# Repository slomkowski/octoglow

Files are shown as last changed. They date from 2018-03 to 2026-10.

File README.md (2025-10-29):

# Octoglow VFD - Fallout-inspired post-apocalyptic display

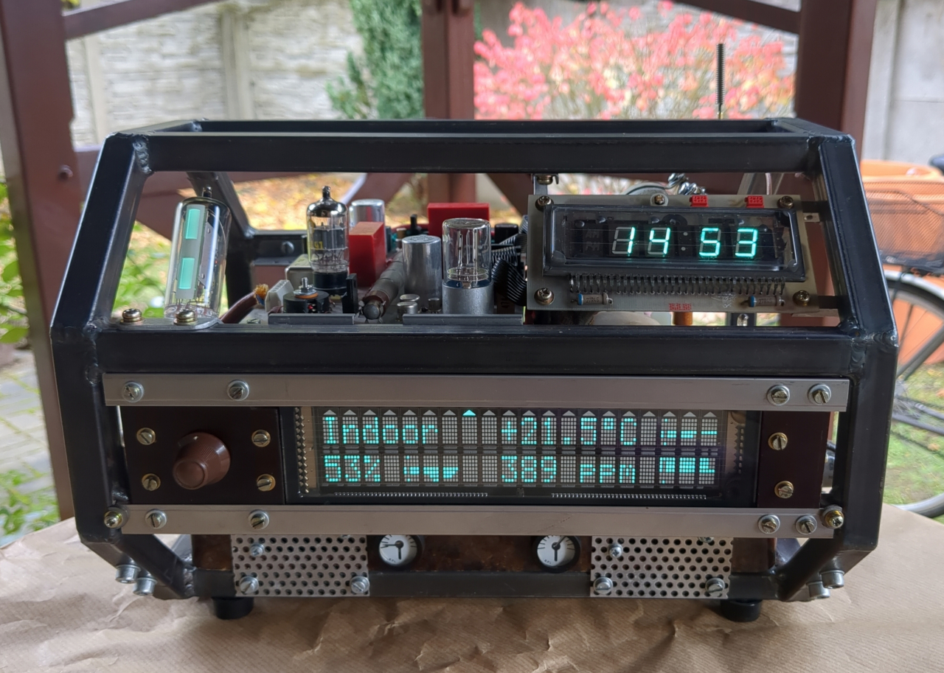
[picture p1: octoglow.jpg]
Overview


Design files of Octoglow, the post-apocalyptic desktop display device. Detailed article [published on my website](https://slomkowski.eu/octoglow-vfd-fallout-inspired-display/).

(C) Michał Słomkowski

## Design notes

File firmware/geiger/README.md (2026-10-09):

# Octoglow VFD - Geiger counter and magic eye board firmware

Written in C++ for MSP430. Depends on *libfixmath* to perform fixed-point arithmetic.

More details under https://slomkowski.eu/octoglow-vfd-fallout-inspired-display/

Tests (`test/`) run on the host with GoogleTest, ASan and UBSan.

## Bootloader

The firmware can be updated over I2C. The bootloader in `bootloader/` is a C++ port of
[twiboot](https://github.com/orempel/twiboot) (GPLv2) for MSP430G2553 with USCI_B0, compatible with its protocol,
like the ones of the clock display and the front display. MSP430 has no boot section, so the bootloader lives at the end
of the flash (`0xFC00`-`0xFFFF`, `BOOTLOADER_START` in `CMakeLists.txt`) together with the real vector table.
The reset vector starts the bootloader, the other vectors jump through the vector table of the application,
which is linked just below the bootloader (`0xFBE0`, see `msp430/application.ld.in`); it costs 3 cycles per interrupt.
The bootloader is never erased. The application is limited to 15 kB including its vector table, enforced by the linker.
The protocol logic (`bootloader/twiboot.cpp`) is covered by the host tests.

* After every reset, the bootloader listens on I2C address `0x19` for 1 s, then starts the application.
  The PWM outputs of the inverters and the heaters of the magic eye are switched off meanwhile.
* The application enters the bootloader on command `ENTER_BOOTLOADER` (`0x08`) with payload `BOOT`:
  it replies and resets (invalid watchdog password) 100 ms later.
* The addresses of the protocol are relative to the start of the flash (`0xC000`), the host subtracts it.
  The page has 64 bytes, the 512-byte segment is erased when its first page is written. The page is written after STOP,
  the host waits 30 ms before reading it back.
* Writing page 0 erases the vector table of the application, its reset vector is written as the last page.
  Without it, the bootloader doesn't time out, so an interrupted update can be repeated.
* The information memory isn't touched, the segment A holds the DCO calibration both the bootloader and the
  application rely on.

First installation (programmer): `burn.sh` writes the application and the bootloader.
Note that programming only the application with `mspdebug prog` erases the bootloader.

Update over I2C:

* `burn-over-ssh.sh` builds the firmware and burns it with `octoglowd --burn-firmware geiger` on the `octoglow` host.
* `flash-over-i2c.sh <app.hex> <bus>` on the host, with *octoglowd* stopped, uses the twiboot tool.

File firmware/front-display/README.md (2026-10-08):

# Octoglow VFD - main display board firmware

More details under https://slomkowski.eu/octoglow-vfd-fallout-inspired-display/

Compiled under *avr-gcc*, *CMake* required. Tests (`test/`) run on the host with GoogleTest, ASan and UBSan.

## Display timing

The display is multiplexed: each of the 40 characters gets a 130 µs slot timed by Timer1 (192 Hz for the whole
display). The brightness is the on-time of CL (PB2, OC1B), cleared by Timer1 in hardware, so neither the brightness
nor the refresh rate depends on the generated code. The scrolling text moves by one column every 39 ms, counted
by the 1 ms tick of Timer0. The values reproduce the firmware which timed both by the code (the -O2 build).

## Bootloader

The firmware can be updated over I2C. The bootloader in `bootloader/` is a C++ port of
[twiboot](https://github.com/orempel/twiboot) (GPLv2) for ATmega88P with the TWI peripheral, compatible with its
protocol and host tool, like the one of the clock display. It lives in the boot section at `0x1800`-`0x1FFF`
(`BOOTSZ` = 1024 words), `BOOTRST` fuse makes every reset start it, so the vector table isn't patched.
The application is limited to 6144 bytes, enforced by the linker. The protocol logic (`bootloader/twiboot.cpp`)
is covered by the host tests.

* After every reset, the bootloader listens on I2C address `0x15` for 1 s, then starts the application.
  Meanwhile, the display shows `BOOTLOADER`, the upper bar blinks while the host talks to it.
* The application enters the bootloader on command `ENTER_BOOTLOADER` (`0x0a`) with payload `BOOT`:
  it replies, shows `Entering bootloader`, stops feeding the watchdog and resets within 250 ms.

First installation (ISP): `burn.sh` writes `octoglow-front-display-avr-with-bootloader.hex` (application + bootloader)
and sets `efuse` to `0xf8` (`BOOTRST` programmed, `BOOTSZ` = 1024 words).
Note that flashing only `octoglow-front-display-avr.hex` with ISP erases the bootloader.

Update over I2C:

* `burn-over-ssh.sh` builds the firmware and burns it with `octoglowd --burn-firmware front-display` on the `octoglow` host.
* `flash-over-i2c.sh <app.hex> <bus>` on the host, with *octoglowd* stopped, uses the twiboot tool.

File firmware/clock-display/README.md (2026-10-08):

# Octoglow VFD - clock display board firmware

Compiled under *avr-gcc*, *CMake* required. *burn.sh* - flashing.

More details under https://slomkowski.eu/octoglow-vfd-fallout-inspired-display/

## Bootloader

The firmware can be updated over I2C. The bootloader in `bootloader/` is a C++ port of
[twiboot](https://github.com/orempel/twiboot) (GPLv2) reduced to ATtiny461A with USI, compatible with its protocol
and host tool. ATtiny461A has no boot section, so the bootloader lives at `0x0C40`-`0x0FFF` and patches the
vector table: the reset vector jumps to the bootloader and the `EE_RDY` vector (must not be used by the
application) jumps to the application. The application is limited to 3136 bytes, enforced by the linker.
USI pins, register settings and both I2C addresses are shared by the application and the bootloader in `common/usi.hpp`.

* After every reset, the bootloader listens on I2C address `0x11` for 1 s, then starts the application.
  Meanwhile, the display shows `BOOT` (8, 0, 0 and T as a mirrored 7), the dots blink while the host talks to it.
* The application enters the bootloader on command `ENTER_BOOTLOADER` (`0x07`) with payload `BOOT`:
  it replies, stops feeding the watchdog and resets within 250 ms.

First installation (ISP): `burn.sh` writes `octoglow-clock-display-with-bootloader.hex` (application + bootloader
with the vector table already patched) and sets `efuse` to `0xfe` (self-programming enabled).
Note that flashing only `octoglow-clock-display.hex` with ISP erases the bootloader.

Update over I2C: `flash-over-i2c.sh <app.hex> <bus>` on the host, with *octoglowd* stopped.

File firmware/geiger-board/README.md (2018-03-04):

# Geiger board

todo jak skompilować projekt

* msp430 toolchain
* gtest
* gcc

# Bus pirate example

Write address *0x24*, read *0x25*.

```
W - enable power supply
P - enable pull-up resistors

[ 0x24 1 [ 0x25 r:8 ] - read device state
[ 0x24 2 [ 0x25 r:6 ]

```

## Animation test - `animationtest`

This program was used to easily test magic eye animation procedure. Uses code from `libsrc`. Requires SDL2 library.

* space - simulate Geiger count
* Esc - exit

## Animation idea

wartość średnia

## I2C protocol specification

status:
napięcie geiger
status przetwornicy eye
napięcie przetwornicy eye
status kontrolera eye: animation, fixed val
wartość kontrolera eye, jeśli fixed val

status geiger:
ilość zliczeń w bieżącym cyklu
ilość zliczeń w poprzednim cyklu
dł. cyklu w s

jakie komendy:
odczyt statusu:
odczyt statusu geiger
włączenie/wyłączenie oka
reset licznika geigera
tryb pracy oka: tryb + wartość dla fixed

## Read device status

Send *0x1* then read 8 bytes. Structure `DeviceState` is returned.

## Read Geiger counter status

Send *0x2* then read 6 bytes. Structure `GeigerState` is returned.

## Clean Geiger counter status

Clears all counters. Send `0x3`.

## Enable/disable magic eye 

```
0x4 | enabled

enabled:
0 - eye disabled (default)
1 - eye enabled
```

# Set magic eye animation mode

```
0x5 | mode | value

mode:
0 - animation. value is ignored
1 - fixed value

value:
0-255 - DAC output
```

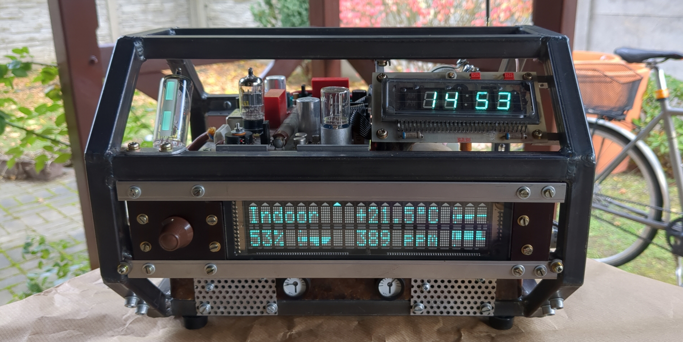
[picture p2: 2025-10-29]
social-preview.jpg

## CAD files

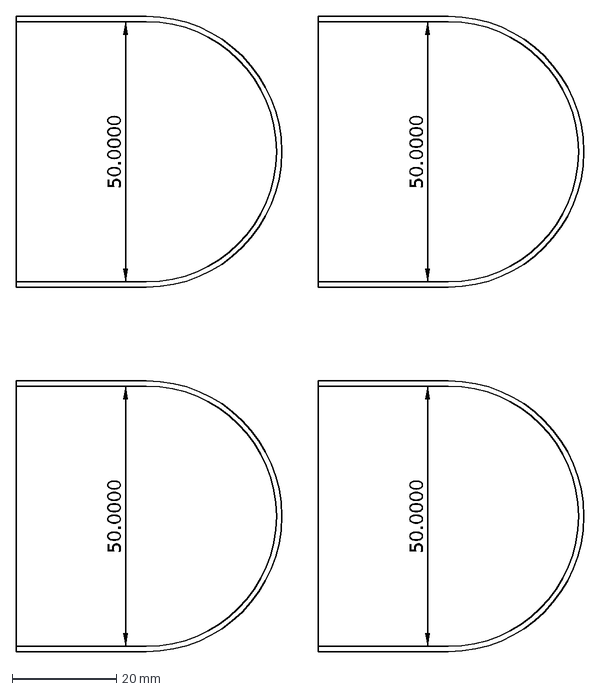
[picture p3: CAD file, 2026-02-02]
case/backlight.dxf
50.0000

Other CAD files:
case/shape.fcstd

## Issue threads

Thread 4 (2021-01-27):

Kotlin native

slomkowski, 2021-01-27:
* linux-i2c - use kernel functions directly
* logging - find other logger
* exposed - probably need to use native SQL driver https://github.com/Dominaezzz/kotlin-sqlite
* jackson & fuel
* konf
* stateful4k - rewrite to Kotlin Multiplatform

Small libs:
* suncalc
* jollyday

slomkowski, 2021-02-15:
* replace java.time with kotlinx date time.
* replace konf with something lightweight?

slomkowski, 2023-06-21:
* Kotlin target: linuxArm32Hfp

slomkowski, 2023-09-20:
linuxArm32Hfp is deprecated in Kotlin Native, so migrating to Kotlin Native it doesn't make sense unless Orange Pi Zero is changed to something else.

Closed 2023-09-20.

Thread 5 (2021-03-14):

Nowa czujka

slomkowski, 2021-03-14:
SP67.

* couple of AGC pulses
* start bit: 8 ms of carrier
* short: 2 ms
* long: 4 ms
* 40 bits
* ostatnie dwa bity z 40 to nr kanału
* bit 12 - manual TX
* bit 13 - weak battery

slomkowski, 2021-04-09:
https://www.chaosgeordend.nl/wordpress/2021/02/18/fanju-temperature-sensor-transmission-protocol/

Closed 2021-07-26.

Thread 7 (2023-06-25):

Remove Java dependencies

slomkowski, 2023-06-25:
With Kotlin libraries ready for Native transition #6.

Pure JVM:

* [ ] Jollyday
* [ ] commons-lang3
* [ ] commons-csv
* [ ] logback
* [ ] ktor - replace with snakeyaml-kmp?

Java with native libraries:
* [ ] exposed with SQLite
* [ ] linux-i2c

Closed 2025-10-05.

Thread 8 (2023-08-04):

Armbian setup

slomkowski, 2023-08-04:
zainstalowane pakiety armbian booworm:
kernel:5.15.93-sunxi
on 6.x kernel wifi doesn't work

powertop
openjdk-17-jre-headless
supervisor
https://github.com/slomkowski/bash-full-of-colors/
 most multitail pydf mtr htop
vim
iputils-ping
gpasswd -a octoglow i2c
btop

Closed 2023-09-20.

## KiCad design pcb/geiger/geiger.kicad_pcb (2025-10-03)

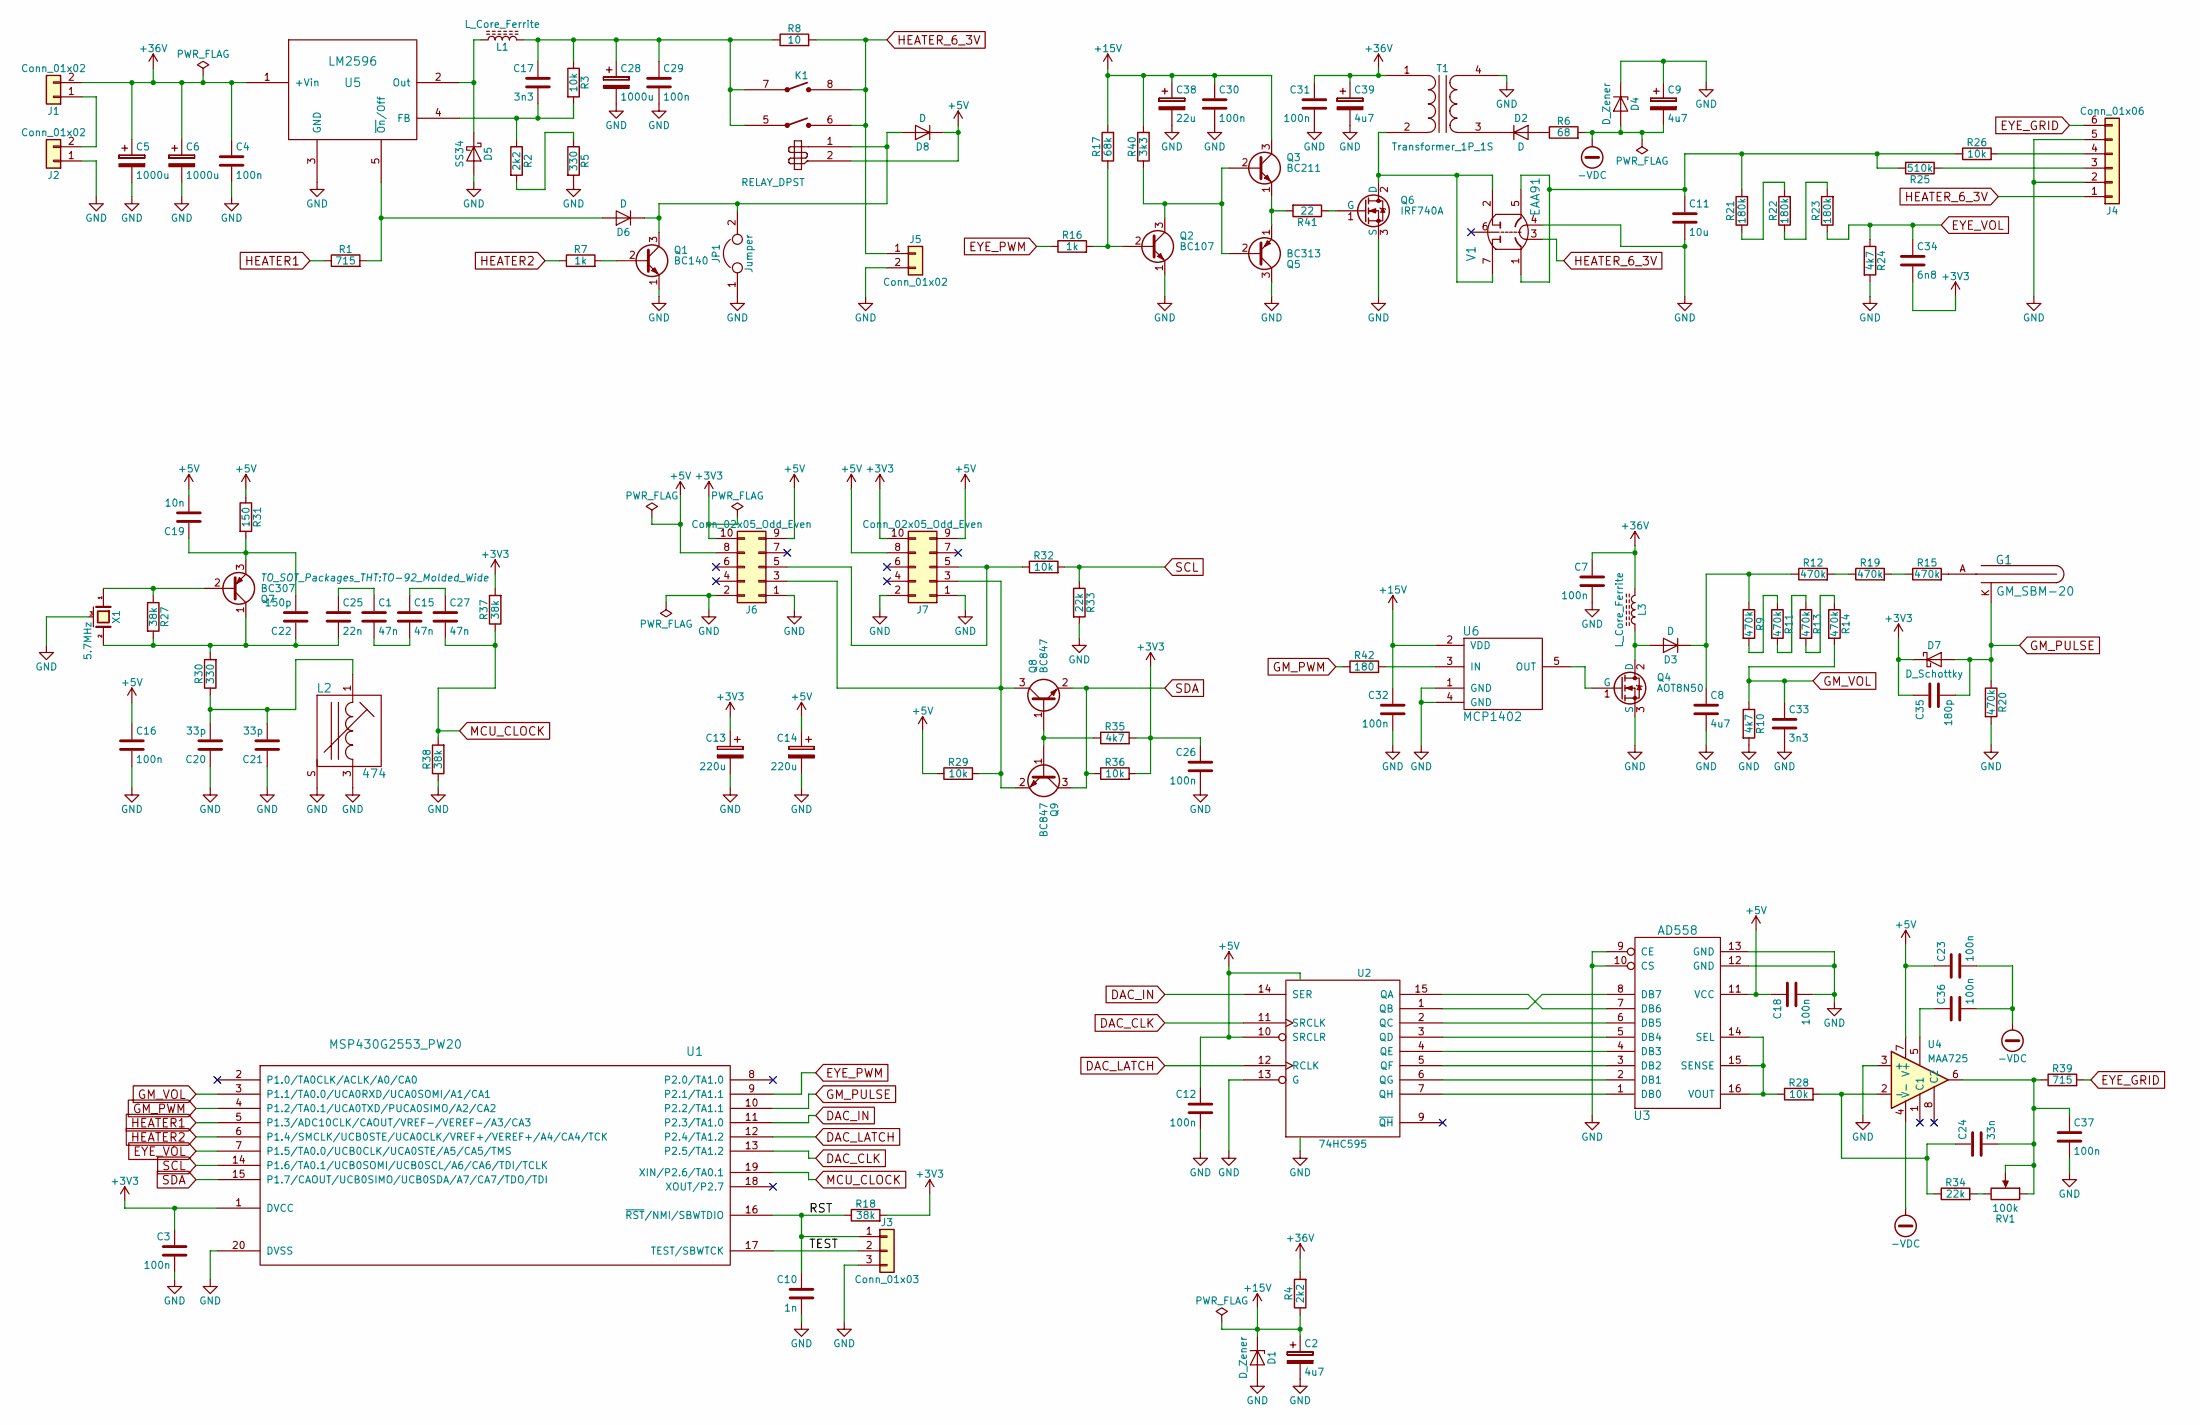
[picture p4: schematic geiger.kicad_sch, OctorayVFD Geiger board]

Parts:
C1, C15, C27: 47n; C_Disc_D5.0mm_W2.5mm_P5.00mm
C2: 4u7; CP_Radial_D6.3mm_P2.50mm
C3, C4, C7, C12, C16, C18, C23, C26, C29, C30, C31, C32, C36, C37: 100n; C_1206_HandSoldering
C5, C6: 1000u; CP_Radial_D16.0mm_P7.50mm
C8: 4u7; C_Rect_L33.0mm_W13.0mm_P27.50mm_MKS4
C9, C39: 4u7; CP_Tantalum_Case-D_EIA-7343-31_Hand
C10: 1n; C_0805_HandSoldering
C11: 10u; C_Rect_L33.0mm_W13.0mm_P27.50mm_MKS4
C13, C14: 220u; CP_Radial_D13.0mm_P5.00mm
C17, C33: 3n3; C_1206_HandSoldering
C19: 10n; C_Disc_D5.0mm_W2.5mm_P5.00mm
C20, C21: 33p; C_Disc_D5.0mm_W2.5mm_P5.00mm
C22: 150p; C_Disc_D5.0mm_W2.5mm_P5.00mm
C24: 33n; C_Disc_D11.0mm_W5.0mm_P5.00mm
C25: 22n; C_Disc_D5.0mm_W2.5mm_P5.00mm
C28: 1000u; CP_Radial_D8.0mm_P3.50mm
C34: 6n8; C_Rect_L9.0mm_W3.2mm_P7.50mm_MKT
C35: 180p; C_Rect_L9.0mm_W3.2mm_P7.50mm_MKT
C38: 22u; CP_Tantalum_Case-B_EIA-3528-21_Hand
D1, D4: D_Zener; D_DO-41_SOD81_P2.54mm_Vertical_AnodeUp
D2, D3: D; D_SMB
D5: SS34; D_SMA-SMB_Universal_Handsoldering
D6, D8: D; D_DO-41_SOD81_P12.70mm_Horizontal
D7: D_Schottky; D_DO-35_SOD27_P10.16mm_Horizontal
G1: GM_SBM-20
J1, J2, J5: Conn_01x02; TerminalBlock_Pheonix_MKDS1.5-2pol
J3: Conn_01x03; Pin_Header_Straight_1x03_Pitch2.54mm
J4: Conn_01x06; TerminalBlock_Pheonix_PT-3.5mm_6pol
J6, J7: Conn_02x05_Odd_Even; Pin_Header_Straight_2x05_Pitch2.54mm
JP1: Jumper; Pin_Header_Straight_1x02_Pitch2.54mm
K1: RELAY_DPST; RELAY_DPST_Telfa_K-8
L1: L_Core_Ferrite; Choke_SMD_12x12mm_h8mm
L2: 474; L_7x7_II
L3: L_Core_Ferrite; F1001_coil
Q1: BC140; TO-39-3
Q2: BC107; TO-18-3
Q3: BC211; TO-39-3
Q4: AOT8N50; TO-220-3_Vertical
Q5: BC313; TO-39-3
Q6: IRF740A; TO-220-3_Vertical
Q7: BC307; TO-92_Molded_Wide
Q8, Q9: BC847; SOT-23
R1: 715; R_Axial_DIN0411_L9.9mm_D3.6mm_P12.70mm_Horizontal
R2: 2k2; R_1206_HandSoldering
R3, R29, R32, R36: 10k; R_1206_HandSoldering
R4: 2k2; R_Axial_DIN0207_L6.3mm_D2.5mm_P10.16mm_Horizontal
R5: 330; R_1206_HandSoldering
R6: 68; R_Axial_DIN0309_L9.0mm_D3.2mm_P12.70mm_Horizontal
R7, R16: 1k; R_Axial_DIN0207_L6.3mm_D2.5mm_P10.16mm_Horizontal
R8: 10; R_Axial_DIN0617_L17.0mm_D6.0mm_P30.48mm_Horizontal
R9, R11, R13, R14, R20: 470k; R_1206_HandSoldering
R10, R24, R35: 4k7; R_1206_HandSoldering
R12, R15, R19: 470k; R_Axial_DIN0309_L9.0mm_D3.2mm_P12.70mm_Horizontal
R17: 68k; R_Axial_DIN0207_L6.3mm_D2.5mm_P10.16mm_Horizontal
R18, R27, R37, R38: 38k; R_1206_HandSoldering
R21, R22, R23: 180k; R_0805_HandSoldering
R25: 510k; R_Axial_DIN0309_L9.0mm_D3.2mm_P15.24mm_Horizontal
R26: 10k; R_Axial_DIN0309_L9.0mm_D3.2mm_P15.24mm_Horizontal
R28: 10k; R_Axial_DIN0207_L6.3mm_D2.5mm_P10.16mm_Horizontal
R30: 330; R_Axial_DIN0207_L6.3mm_D2.5mm_P10.16mm_Horizontal
R31: 150; R_Axial_DIN0207_L6.3mm_D2.5mm_P10.16mm_Horizontal
R33: 22k; R_1206_HandSoldering
R34: 22k; R_Axial_DIN0207_L6.3mm_D2.5mm_P10.16mm_Horizontal
R39: 715; R_Axial_DIN0309_L9.0mm_D3.2mm_P12.70mm_Horizontal
R40: 3k3; R_Axial_DIN0207_L6.3mm_D2.5mm_P10.16mm_Horizontal
R41: 22; R_Axial_DIN0309_L9.0mm_D3.2mm_P12.70mm_Horizontal
R42: 180; R_Axial_DIN0309_L9.0mm_D3.2mm_P15.24mm_Horizontal
RV1: 100k; Potentiometer_Trimmer_Bourns_3006P
T1: Transformer_1P_1S; F1001_trans
U1: MSP430G2553_PW20; DIP-20_W7.62mm_LongPads
U2: 74HC595; DIP-16_W7.62mm_LongPads
U3: AD558; DIP-16_W7.62mm_LongPads
U4: MAA725; TO-5-8_H08C
U5: LM2596; TO-263-5_TabPin3
U6: MCP1402; SOT-23-5_HandSoldering
V1: EAA91; HEPTAL1
X1: 5.7MHz; glass_xtal

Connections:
+3V3: C3.1, C13.1, C26.1, C34.2, C35.1, D7.1 (K), J6.10, J7.10, R18.2, R35.2, R36.2, R37.2, U1.1 (DVCC)
+5V: C12.1, C14.1, C16.1, C18.1, C19.2, C23.1, D8.1 (K), J6.8, J6.9, J7.8, J7.9, K1.2, R29.1, R31.1, U2.10 (SRCLR), U2.16 (VCC), U3.11 (VCC), U4.7 (V+)
+15V: C2.1, C30.1, C32.1, C38.1, D1.1 (K), Q3.3 (C), R4.1, R17.2, R40.2, U6.2 (VDD)
+36V: C4.1, C5.1, C6.1, C7.1, C31.1, C39.1, J1.2, L3.2, R4.2, T1.1 (AA), U5.1 (+Vin)
-VDC: C9.2, C23.2, C36.2, D4.2 (A), R6.2, U4.4 (V-)
/RST: C10.1, J3.1, R18.1, U1.16 (~RST/NMI/SBWTDIO)
/TEST: J3.2, U1.17 (TEST/SBWTCK)
DAC_CLK: U1.13 (P2.5/TA1.2), U2.11 (SRCLK)
DAC_IN: U1.11 (P2.3/TA1.0), U2.14 (SER)
DAC_LATCH: U1.12 (P2.4/TA1.2), U2.12 (RCLK)
EYE_GRID: J4.6, R39.2
EYE_PWM: R16.1, U1.9 (P2.1/TA1.1)
EYE_VOL: C34.1, R23.1, R24.1, U1.7 (P1.5/TA0.0/UCB0CLK/UCA0STE/A5/CA5/TMS)
GM_PULSE: C35.2, D7.2 (A), G1.K, R20.1, U1.10 (P2.2/TA1.1)
GM_PWM: R42.1, U1.4 (P1.2/TA0.1/UCA0TXD/PUCA0SIMO/A2/CA2)
GM_VOL: C33.1, R10.1, R14.2, U1.3 (P1.1/TA0.0/UCA0RXD/UCA0SOMI/A1/CA1)
GND: C2.2, C3.2, C4.2, C5.2, C6.2, C7.2, C8.2, C9.1, C10.2, C11.2, C12.2, C13.2, C14.2, C16.2, C18.2, C20.1, C21.1, C26.2, C28.2, C29.2, C30.2, C31.2, C32.2, C33.2, C37.2, C38.2, C39.2, D1.2 (A), D4.1 (K), D5.2 (A), J2.1, J3.3, J4.2, J4.5, J5.2, J6.1, J6.2, J7.1, J7.2, JP1.1, L2.3, L2.S, Q1.1 (E), Q2.1 (E), Q4.3 (S), Q5.3 (C), Q6.3 (S), R5.2, R10.2, R20.2, R24.2, R33.2, R38.1, T1.4 (SB), U1.20 (DVSS), U2.8 (GND), U2.13 (G), U3.9 (CE), U3.10 (CS), U3.12 (GND), U3.13 (GND), U4.3 (+), U5.3 (GND), U6.1 (GND), U6.4 (GND), V1.4, X1.3 (case)
HEATER1: R1.1, U1.5 (P1.3/ADC10CLK/CAOUT/VREF-/VEREF-/A3/CA3)
HEATER2: R7.1, U1.6 (P1.4/SMCLK/UCB0STE/UCA0CLK/VREF+/VEREF+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)
HEATER_6_3V: J4.1, J5.1, K1.6, K1.8, R8.2, V1.3
MCU_CLOCK: C27.2, R37.1, R38.2, U1.19 (XIN/P2.6/TA0.1)
unnamed: C1.1, C25.1
unnamed: C1.2, C15.2
unnamed: C11.1, R21.2, R25.2, R26.1, V1.1, V1.5
unnamed: C15.1, C27.1
unnamed: C17.1, C28.1, C29.1, K1.5, K1.7, L1.2, R3.1, R8.1
unnamed: C20.2, C21.2, L2.1, R30.1
unnamed: C24.2, C37.1, R39.1, RV1.1, RV1.2, U4.6
unnamed: C36.1, U4.5
unnamed: D2.2 (A), R6.1
unnamed: D2.1 (K), T1.3 (SA)
unnamed: D3.2 (A), L3.1, Q4.2 (D)
unnamed: C8.1, D3.1 (K), R9.1, R12.1
unnamed: D5.1 (K), L1.1, U5.2 (Out)
unnamed: D6.2 (A), R1.2, U5.5 (~On/Off)
unnamed: D6.1 (K), D8.2 (A), JP1.2, K1.1, Q1.3 (C)
unnamed: G1.A, R15.2
unnamed: J1.1, J2.2
unnamed: J4.3, R25.1
unnamed: J4.4, R26.2
unnamed: J6.3, J7.3, Q8.3 (C), Q9.2 (E), R29.2
unnamed: J6.5, J7.5, R32.1
unnamed: Q1.2 (B), R7.2
unnamed: Q2.2 (B), R16.2, R17.1
unnamed: Q2.3 (C), Q3.2 (B), Q5.2 (B), R40.1
unnamed: Q3.1 (E), Q5.1 (E), R41.2
unnamed: Q4.1 (G), U6.5 (OUT)
unnamed: Q6.2 (D), T1.2 (AB), V1.2, V1.7
unnamed: Q6.1 (G), R41.1
unnamed: Q7.2 (B), R27.1, X1.1
unnamed: C22.1, C25.2, Q7.1 (C), R27.2, R30.2, X1.2
unnamed: C19.1, C22.2, Q7.3 (E), R31.2
unnamed: Q8.1 (B), Q9.1 (B), R35.1
unnamed: R2.2, R5.1
unnamed: R9.2, R11.1
unnamed: R11.2, R13.1
unnamed: R12.2, R19.1
unnamed: R13.2, R14.1
unnamed: R15.1, R19.2
unnamed: R21.1, R22.2
unnamed: R22.1, R23.2
unnamed: R34.2, RV1.3
unnamed: U2.15 (QA), U3.7 (DB6)
unnamed: U2.1 (QB), U3.8 (DB7)
unnamed: U2.2 (QC), U3.6 (DB5)
unnamed: U2.3 (QD), U3.5 (DB4)
unnamed: U2.4 (QE), U3.4 (DB3)
unnamed: U2.5 (QF), U3.3 (DB2)
unnamed: U2.6 (QG), U3.2 (DB1)
unnamed: U2.7 (QH), U3.1 (DB0)
unnamed: R28.1, U3.14 (SEL), U3.15 (SENSE), U3.16 (VOUT)
unnamed: C24.1, R28.2, R34.1, U4.2 (-)
unnamed: C17.2, R2.1, R3.2, U5.4 (FB)
unnamed: R42.2, U6.3 (IN)
SCL: R32.2, R33.1, U1.14 (P1.6/TA0.1/UCB0SOMI/UCB0SCL/A6/CA6/TDI/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)
SDA: Q8.2 (E), Q9.3 (C), R36.1, U1.15 (P1.7/CAOUT/UCB0SIMO/UCB0SDA/A7/CA7/TDO/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)

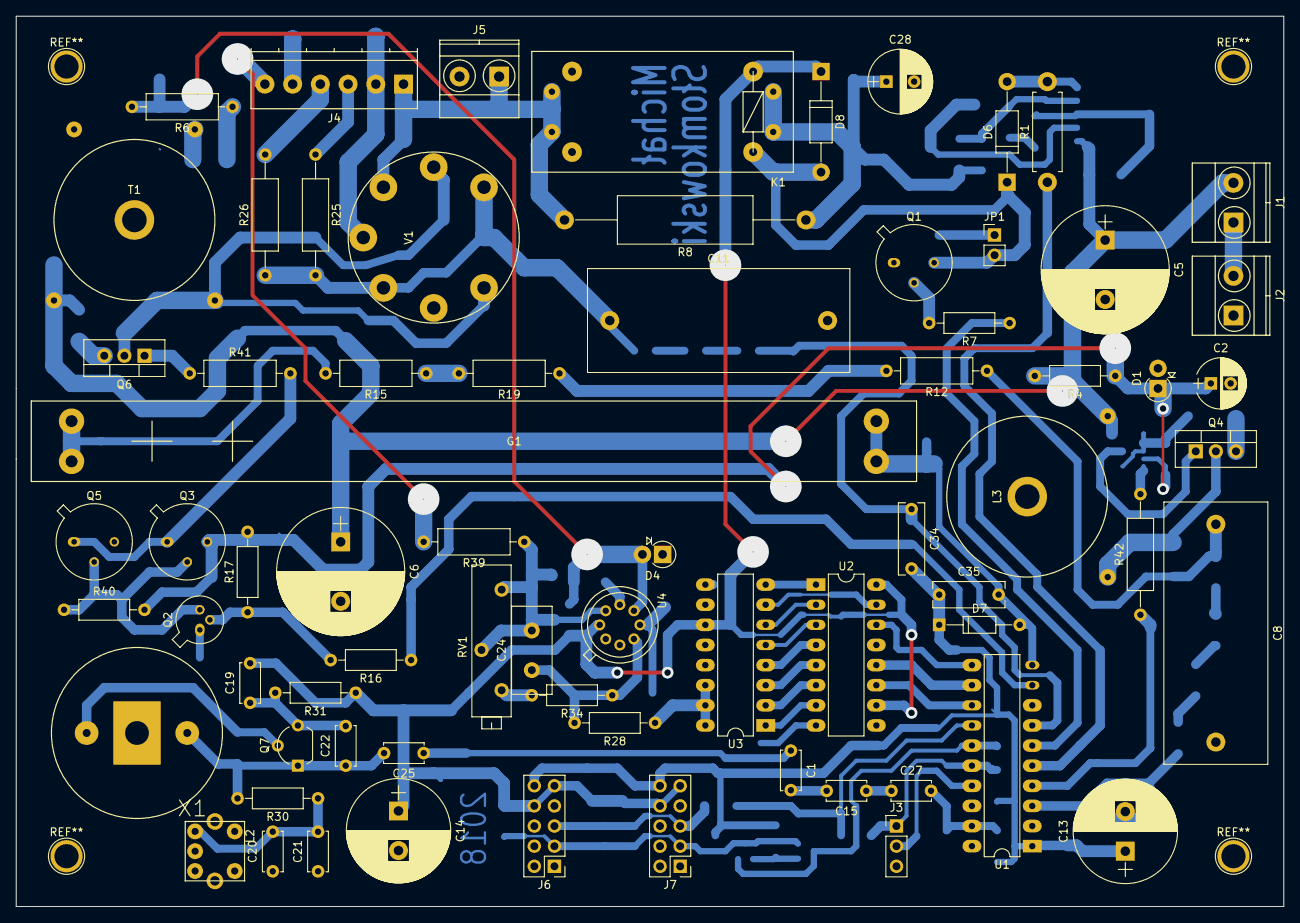
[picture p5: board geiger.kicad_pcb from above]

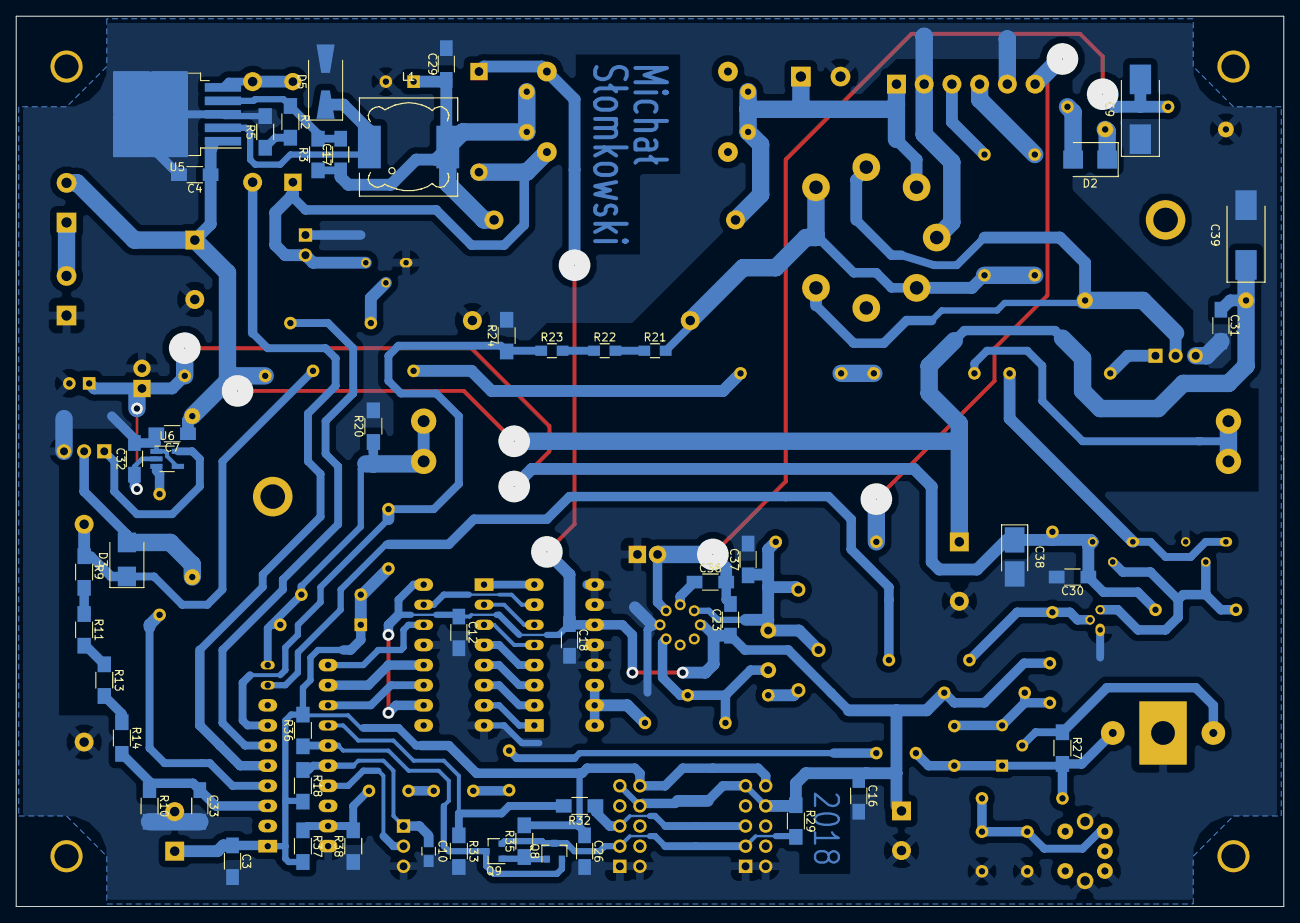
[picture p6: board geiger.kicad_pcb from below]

Board: 2 copper layers, 160.0 x 112.4 mm, 121 parts (50 on the bottom side), 76 nets.

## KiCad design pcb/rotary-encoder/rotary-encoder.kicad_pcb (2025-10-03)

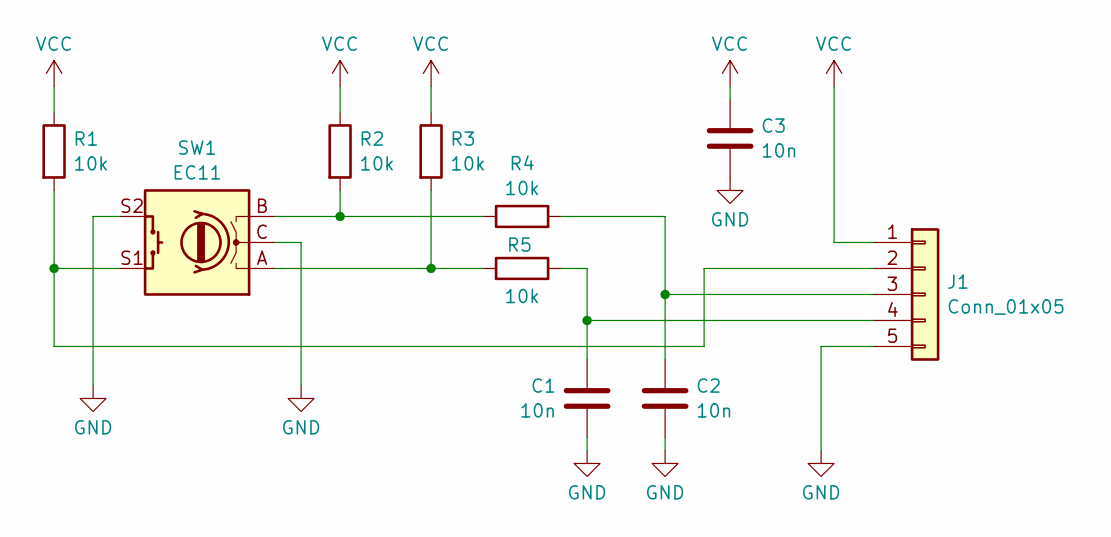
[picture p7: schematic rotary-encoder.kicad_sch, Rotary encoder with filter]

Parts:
C1, C2, C3: 10n; C_1206_3216Metric_Pad1.33x1.80mm_HandSolder
J1: Conn_01x05; PinHeader_1x05_P2.54mm_Horizontal
R1, R2, R3, R4, R5: 10k; R_1206_3216Metric_Pad1.30x1.75mm_HandSolder
SW1: EC11; RotaryEncoder_Alps_EC12E-Switch_Vertical_H20mm

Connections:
GND: C1.2, C2.2, C3.2, J1.5, SW1.C, SW1.S2
unnamed: J1.2, R1.2, SW1.S1
unnamed: C2.1, J1.3, R4.2
unnamed: C1.1, J1.4, R5.1
unnamed: R2.2, R4.1, SW1.B
unnamed: R3.2, R5.2, SW1.A
VCC: C3.1, J1.1, R1.1, R2.1, R3.1

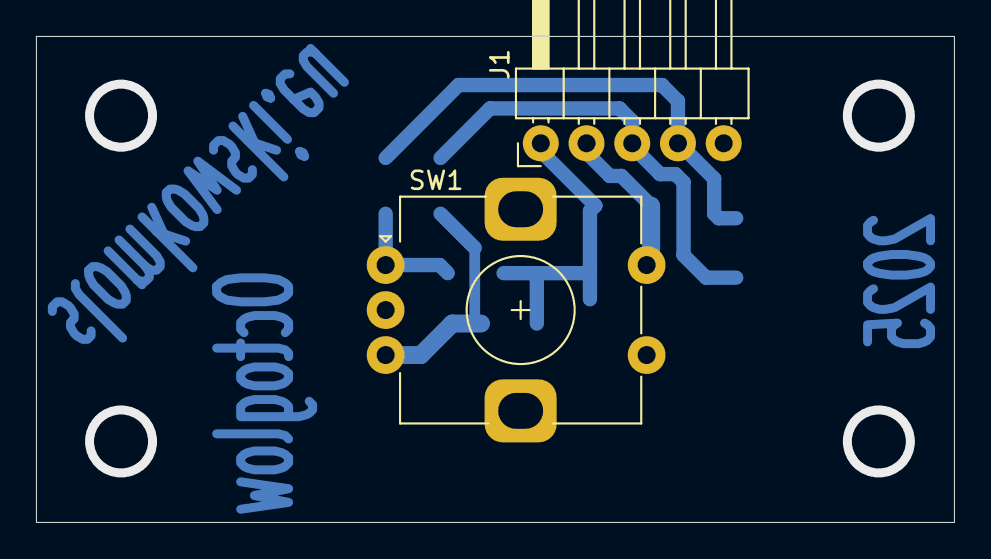
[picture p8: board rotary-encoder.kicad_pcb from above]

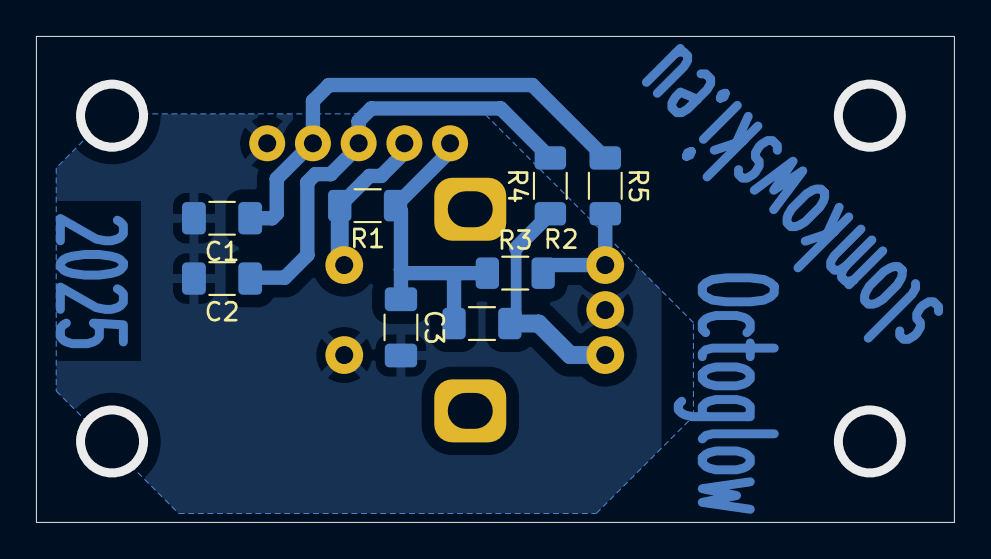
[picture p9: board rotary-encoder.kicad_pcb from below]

Board: 2 copper layers, 51.0 x 27.0 mm, 10 parts (8 on the bottom side), 7 nets.

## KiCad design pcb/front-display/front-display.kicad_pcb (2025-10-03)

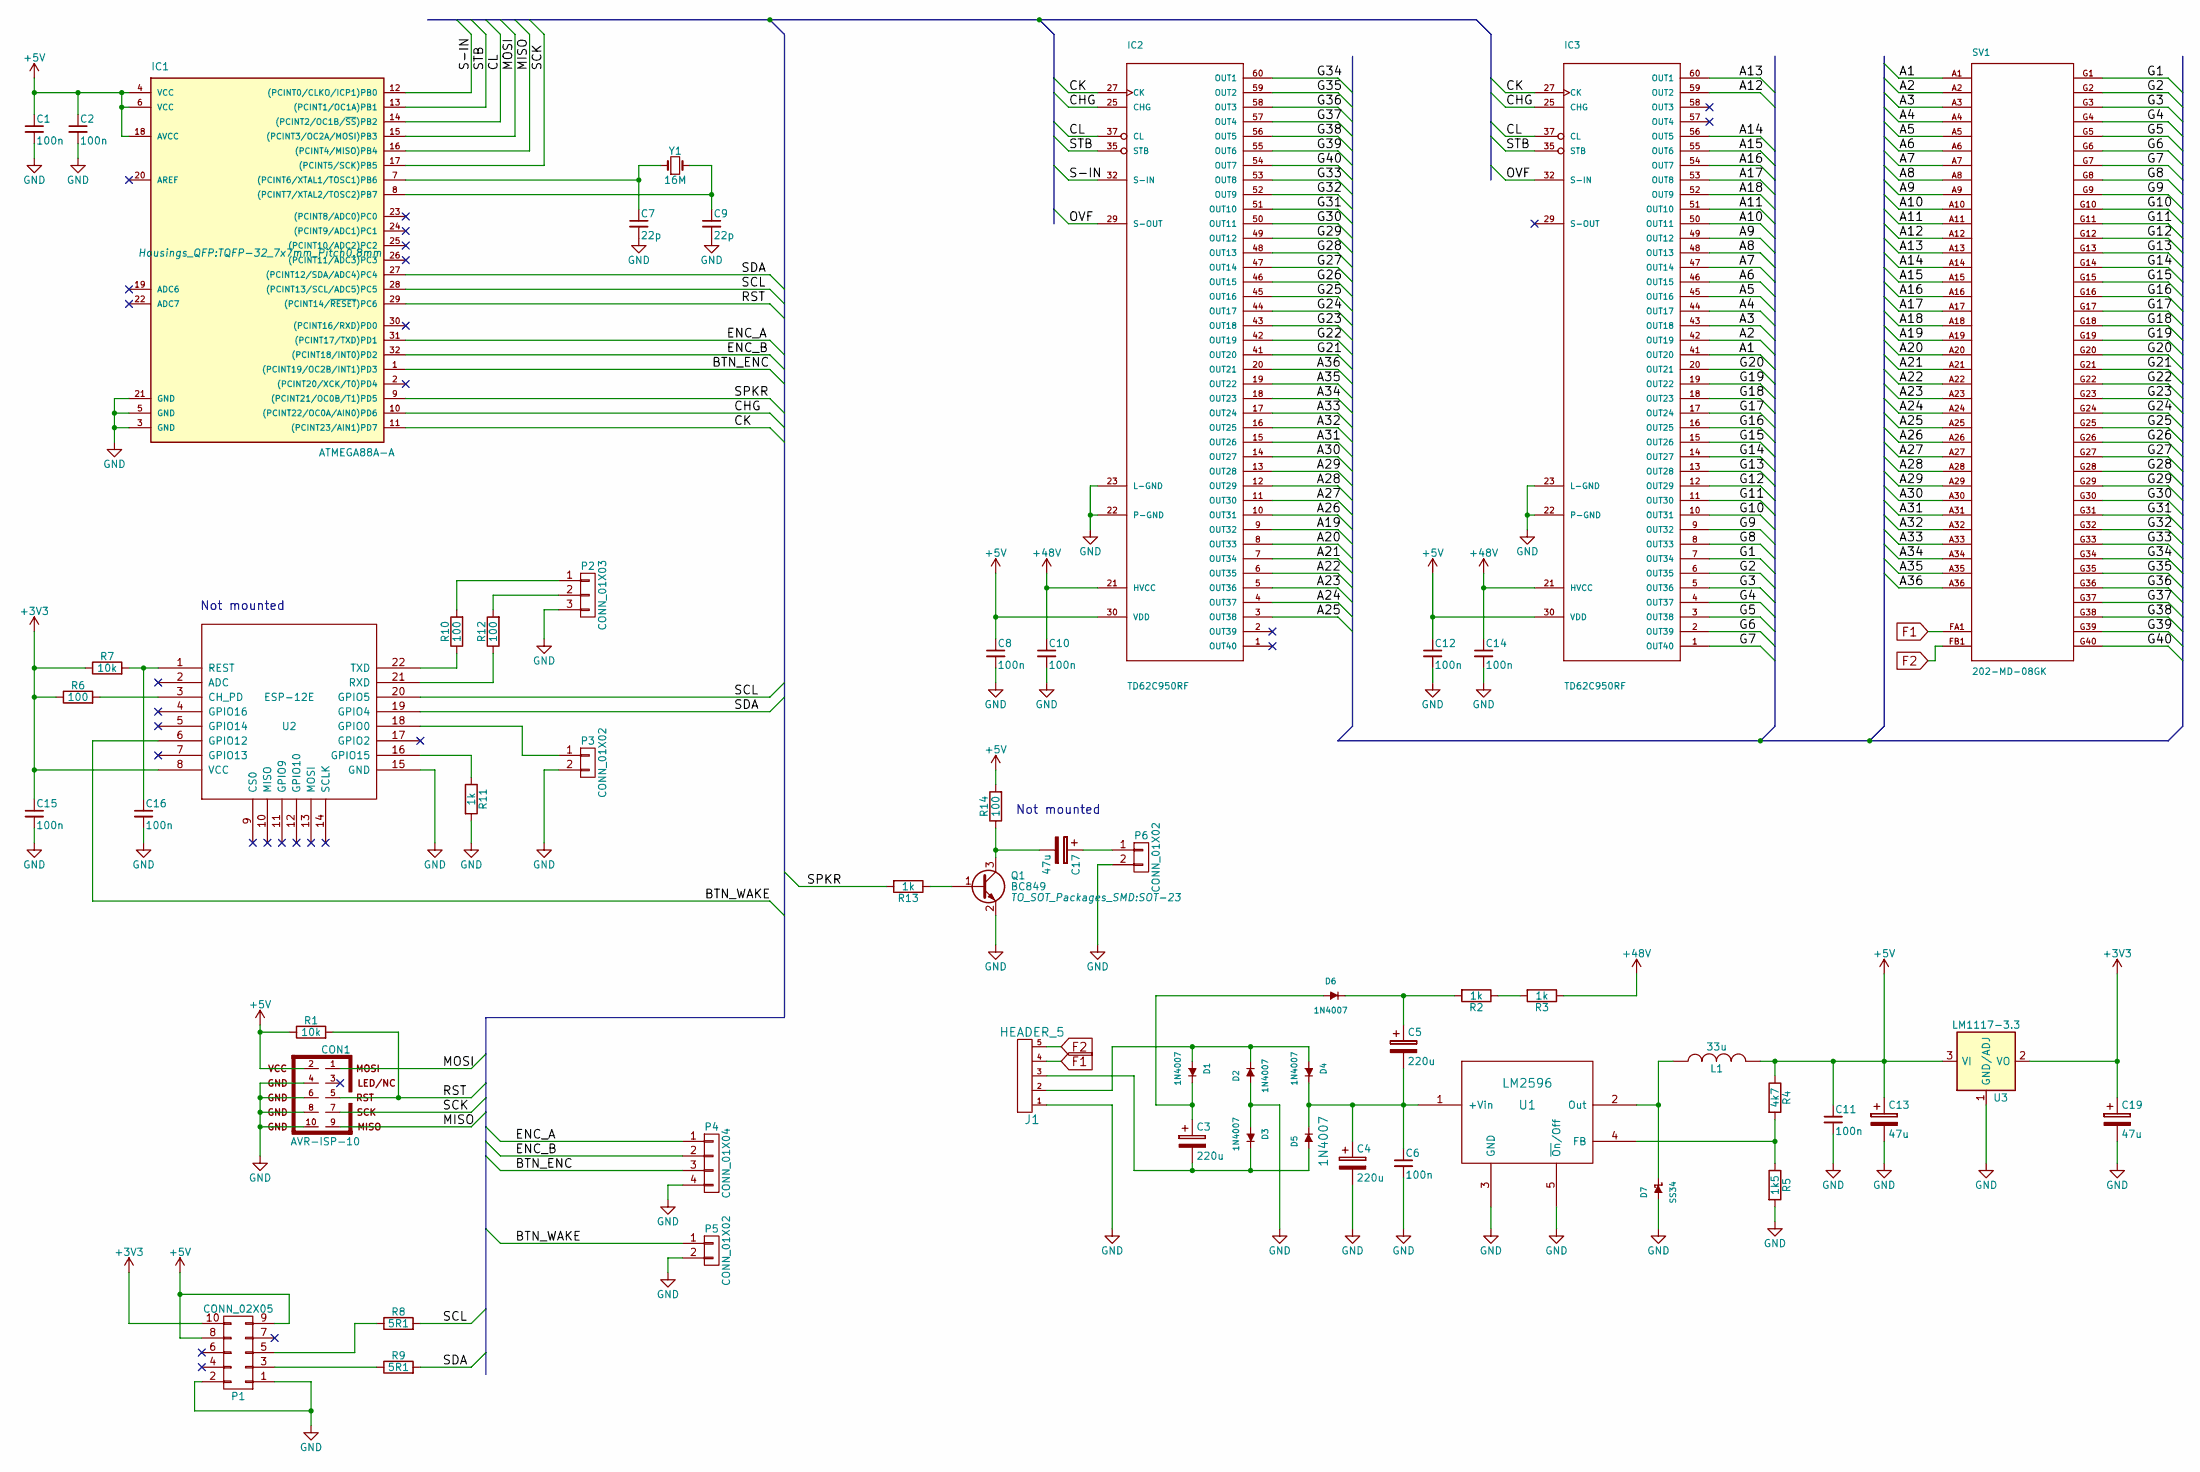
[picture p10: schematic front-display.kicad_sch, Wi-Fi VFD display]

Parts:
C1, C2, C6, C8, C10, C11, C12, C14, C15, C16: 100n; C_1206_HandSoldering
C3, C4, C5: 220u; c_elec_10x10
C7, C9: 22p; C_0805_HandSoldering
C13, C17, C19: 47u; c_elec_8x10.5
CON1: AVR-ISP-10; Pin_Header_Straight_2x05
D1, D2, D3, D4, D5, D6: 1N4007; SMA-SMB_Universal_Handsoldering
D7: SS34; SMA-SMB_Universal_Handsoldering
IC1: ATMEGA88A-A; TQFP-32_7x7mm_Pitch0.8mm
IC2, IC3: TD62C950RF; TD62C950RF-SSOP60-P-0.65A
J1: HEADER_5; TerminalBlock_Pheonix_MKDS1.5-5pol
L1: 33u; Choke_SMD_12x12mm_h8mm
P1: CONN_02X05; Pin_Header_Straight_2x05
P2: CONN_01X03; Pin_Header_Straight_1x03
P3, P5, P6: CONN_01X02; Pin_Header_Straight_1x02
P4: CONN_01X04; Pin_Header_Straight_1x04
Q1: BC849; SOT-23
R1, R7: 10k; R_1206_HandSoldering
R2, R3, R11, R13: 1k; R_1206_HandSoldering
R4: 4k7; R_1206_HandSoldering
R5: 1k5; R_1206_HandSoldering
R6, R10, R12, R14: 100; R_1206_HandSoldering
R8, R9: 5R1; R_1206_HandSoldering
SV1: 202-MD-08GK; futaba-vfd-VFD1
U1: LM2596; TO-263-5Lead
U2: ESP-12E
U3: LM1117-3.3; SOT-223
Y1: 16M; crystal-hc49sm

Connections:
+3V3: C15.1, C19.1, P1.10, R6.1, R7.1, U2.8 (VCC), U3.2 (VO), U3.4 (VO)
+5V: C1.1, C2.1, C8.1, C11.1, C12.1, C13.1, CON1.2, IC1.4 (VCC), IC1.6 (VCC), IC1.18 (AVCC), IC2.30 (VDD), IC2.31 (VDD), IC3.30 (VDD), IC3.31 (VDD), L1.2, P1.8, P1.9, R1.1, R4.1, R14.2, U3.3 (VI)
+48V: C10.1, C14.1, IC2.21 (HVCC), IC2.40 (HVCC), IC3.21 (HVCC), IC3.40 (HVCC), R3.1
/A1: IC3.41 (OUT20), SV1.A1
/A2: IC3.42 (OUT19), SV1.A2
/A3: IC3.43 (OUT18), SV1.A3
/A4: IC3.44 (OUT17), SV1.A4
/A5: IC3.45 (OUT16), SV1.A5
/A6: IC3.46 (OUT15), SV1.A6
/A7: IC3.47 (OUT14), SV1.A7
/A8: IC3.48 (OUT13), SV1.A8
/A9: IC3.49 (OUT12), SV1.A9
/A10: IC3.50 (OUT11), SV1.A10
/A11: IC3.51 (OUT10), SV1.A11
/A12: IC3.59 (OUT2), SV1.A12
/A13: IC3.60 (OUT1), SV1.A13
/A14: IC3.56 (OUT5), SV1.A14
/A15: IC3.55 (OUT6), SV1.A15
/A16: IC3.54 (OUT7), SV1.A16
/A17: IC3.53 (OUT8), SV1.A17
/A18: IC3.52 (OUT9), SV1.A18
/A19: IC2.9 (OUT32), SV1.A19
/A20: IC2.8 (OUT33), SV1.A20
/A21: IC2.7 (OUT34), SV1.A21
/A22: IC2.6 (OUT35), SV1.A22
/A23: IC2.5 (OUT36), SV1.A23
/A24: IC2.4 (OUT37), SV1.A24
/A25: IC2.3 (OUT38), SV1.A25
/A26: IC2.10 (OUT31), SV1.A26
/A27: IC2.11 (OUT30), SV1.A27
/A28: IC2.12 (OUT29), SV1.A28
/A29: IC2.13 (OUT28), SV1.A29
/A30: IC2.14 (OUT27), SV1.A30
/A31: IC2.15 (OUT26), SV1.A31
/A32: IC2.16 (OUT25), SV1.A32
/A33: IC2.17 (OUT24), SV1.A33
/A34: IC2.18 (OUT23), SV1.A34
/A35: IC2.19 (OUT22), SV1.A35
/A36: IC2.20 (OUT21), SV1.A36
/BTN_ENC: IC1.1 ((PCINT19/OC2B/INT1)PD3), P4.3
/BTN_WAKE: P5.1, U2.6 (GPIO12)
/CHG: IC1.10 ((PCINT22/OC0A/AIN0)PD6), IC2.25 (CHG), IC3.25 (CHG)
/CK: IC1.11 ((PCINT23/AIN1)PD7), IC2.27 (CK), IC3.27 (CK)
/CL: IC1.14 ((PCINT2/OC1B/~SS)PB2), IC2.37 (CL), IC3.37 (CL)
/ENC_A: IC1.31 ((PCINT17/TXD)PD1), P4.1
/ENC_B: IC1.32 ((PCINT18/INT0)PD2), P4.2
/G1: IC3.7 (OUT34), SV1.G1
/G2: IC3.6 (OUT35), SV1.G2
/G3: IC3.5 (OUT36), SV1.G3
/G4: IC3.4 (OUT37), SV1.G4
/G5: IC3.3 (OUT38), SV1.G5
/G6: IC3.2 (OUT39), SV1.G6
/G7: IC3.1 (OUT40), SV1.G7
/G8: IC3.8 (OUT33), SV1.G8
/G9: IC3.9 (OUT32), SV1.G9
/G10: IC3.10 (OUT31), SV1.G10
/G11: IC3.11 (OUT30), SV1.G11
/G12: IC3.12 (OUT29), SV1.G12
/G13: IC3.13 (OUT28), SV1.G13
/G14: IC3.14 (OUT27), SV1.G14
/G15: IC3.15 (OUT26), SV1.G15
/G16: IC3.16 (OUT25), SV1.G16
/G17: IC3.17 (OUT24), SV1.G17
/G18: IC3.18 (OUT23), SV1.G18
/G19: IC3.19 (OUT22), SV1.G19
/G20: IC3.20 (OUT21), SV1.G20
/G21: IC2.41 (OUT20), SV1.G21
/G22: IC2.42 (OUT19), SV1.G22
/G23: IC2.43 (OUT18), SV1.G23
/G24: IC2.44 (OUT17), SV1.G24
/G25: IC2.45 (OUT16), SV1.G25
/G26: IC2.46 (OUT15), SV1.G26
/G27: IC2.47 (OUT14), SV1.G27
/G28: IC2.48 (OUT13), SV1.G28
/G29: IC2.49 (OUT12), SV1.G29
/G30: IC2.50 (OUT11), SV1.G30
/G31: IC2.51 (OUT10), SV1.G31
/G32: IC2.52 (OUT9), SV1.G32
/G33: IC2.53 (OUT8), SV1.G33
/G34: IC2.60 (OUT1), SV1.G34
/G35: IC2.59 (OUT2), SV1.G35
/G36: IC2.58 (OUT3), SV1.G36
/G37: IC2.57 (OUT4), SV1.G37
/G38: IC2.56 (OUT5), SV1.G38
/G39: IC2.55 (OUT6), SV1.G39
/G40: IC2.54 (OUT7), SV1.G40
/MISO: CON1.9, IC1.16 ((PCINT4/MISO)PB4)
/MOSI: CON1.1, IC1.15 ((PCINT3/OC2A/MOSI)PB3)
/OVF: IC2.29 (S-OUT), IC3.32 (S-IN)
/RST: CON1.5, IC1.29 ((PCINT14/~RESET)PC6), R1.2
/S-IN: IC1.12 ((PCINT0/CLKO/ICP1)PB0), IC2.32 (S-IN)
/SCK: CON1.7, IC1.17 ((PCINT5/SCK)PB5)
/SCL: IC1.28 ((PCINT13/SCL/ADC5)PC5), R8.2, U2.20 (GPIO5)
/SDA: IC1.27 ((PCINT12/SDA/ADC4)PC4), R9.2, U2.19 (GPIO4)
/SPKR: IC1.9 ((PCINT21/OC0B/T1)PD5), R13.2
/STB: IC1.13 ((PCINT1/OC1A)PB1), IC2.35 (STB), IC3.35 (STB)
F1: J1.4, SV1.FA1 (F1), SV1.FA2 (F1), SV1.FA3 (F1)
F2: J1.5, SV1.FB1 (F2), SV1.FB2 (F2), SV1.FB3 (F2)
GND: C1.2, C2.2, C4.2, C6.2, C7.2, C8.2, C9.2, C10.2, C11.2, C12.2, C13.2, C14.2, C15.2, C16.2, C19.2, CON1.4, CON1.6, CON1.8, CON1.10, D2.1 (A), D3.1 (A), D7.1 (A), IC1.3 (GND), IC1.5 (GND), IC1.21 (GND), IC2.22 (P-GND), IC2.23 (L-GND), IC2.38 (L-GND), IC2.39 (P-GND), IC3.22 (P-GND), IC3.23 (L-GND), IC3.38 (L-GND), IC3.39 (P-GND), J1.1, P1.1, P1.2, P2.3, P3.2, P4.4, P5.2, P6.2, Q1.2 (E), R5.2, R11.2, U1.3 (GND), U1.5 (~On/Off), U2.15 (GND), U3.1 (GND/ADJ)
unnamed: D1.1 (A), D2.2 (K), D4.1 (A), J1.2
unnamed: C3.1, D1.2 (K), D6.1 (A)
unnamed: C3.2, D3.2 (K), D5.1 (A), J1.3
unnamed: C4.1, C5.2, C6.1, D4.2 (K), D5.2 (K), U1.1 (+Vin)
unnamed: C5.1, D6.2 (K), R2.2
unnamed: D7.2 (K), L1.1, U1.2 (Out)
unnamed: C7.1, IC1.7 ((PCINT6/XTAL1/TOSC1)PB6), Y1.1
unnamed: C9.1, IC1.8 ((PCINT7/XTAL2/TOSC2)PB7), Y1.2
unnamed: P1.3, R9.1
unnamed: P1.5, R8.1
unnamed: P2.1, R10.2
unnamed: P2.2, R12.2
unnamed: P3.1, U2.18 (GPIO0)
unnamed: C17.1, P6.1
unnamed: Q1.1 (B), R13.1
unnamed: C17.2, Q1.3 (C), R14.1
unnamed: R2.1, R3.2
unnamed: R4.2, R5.1, U1.4 (FB)
unnamed: R6.2, U2.3 (CH_PD)
unnamed: R11.1, U2.16 (GPIO15)
unnamed: C16.1, R7.2, U2.1 (REST)
unnamed: R12.1, U2.21 (RXD)
unnamed: R10.1, U2.22 (TXD)

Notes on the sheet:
Not mounted
Not mounted

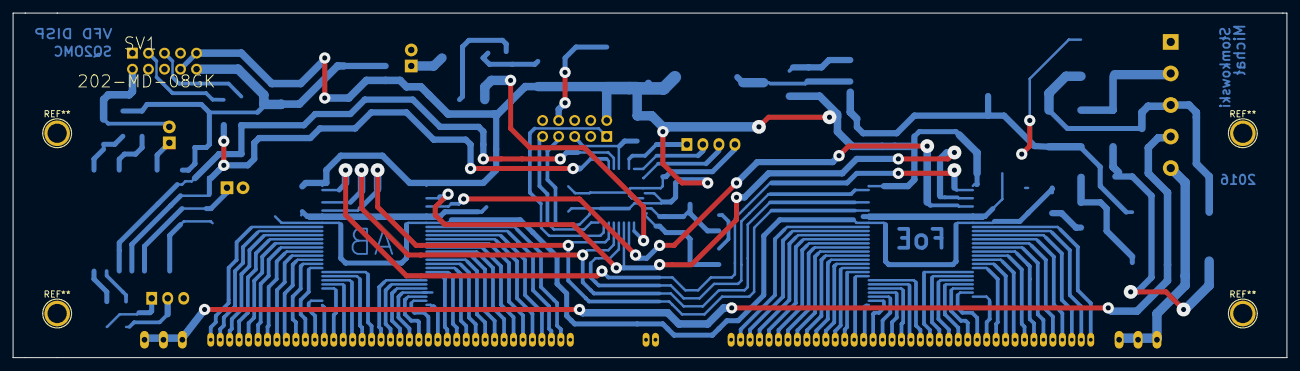
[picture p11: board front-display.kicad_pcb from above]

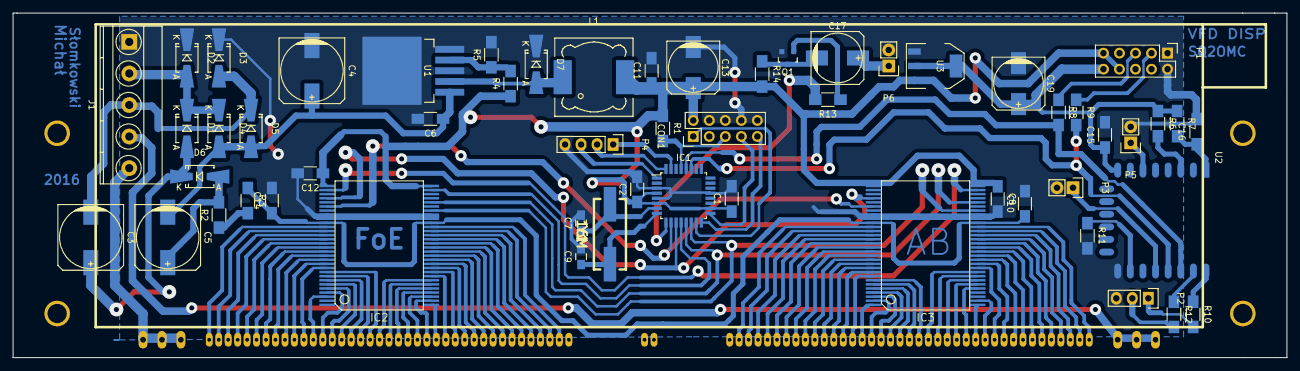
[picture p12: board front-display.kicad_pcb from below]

Board: 2 copper layers, 201.9 x 54.6 mm, 57 parts (56 on the bottom side), 122 nets.

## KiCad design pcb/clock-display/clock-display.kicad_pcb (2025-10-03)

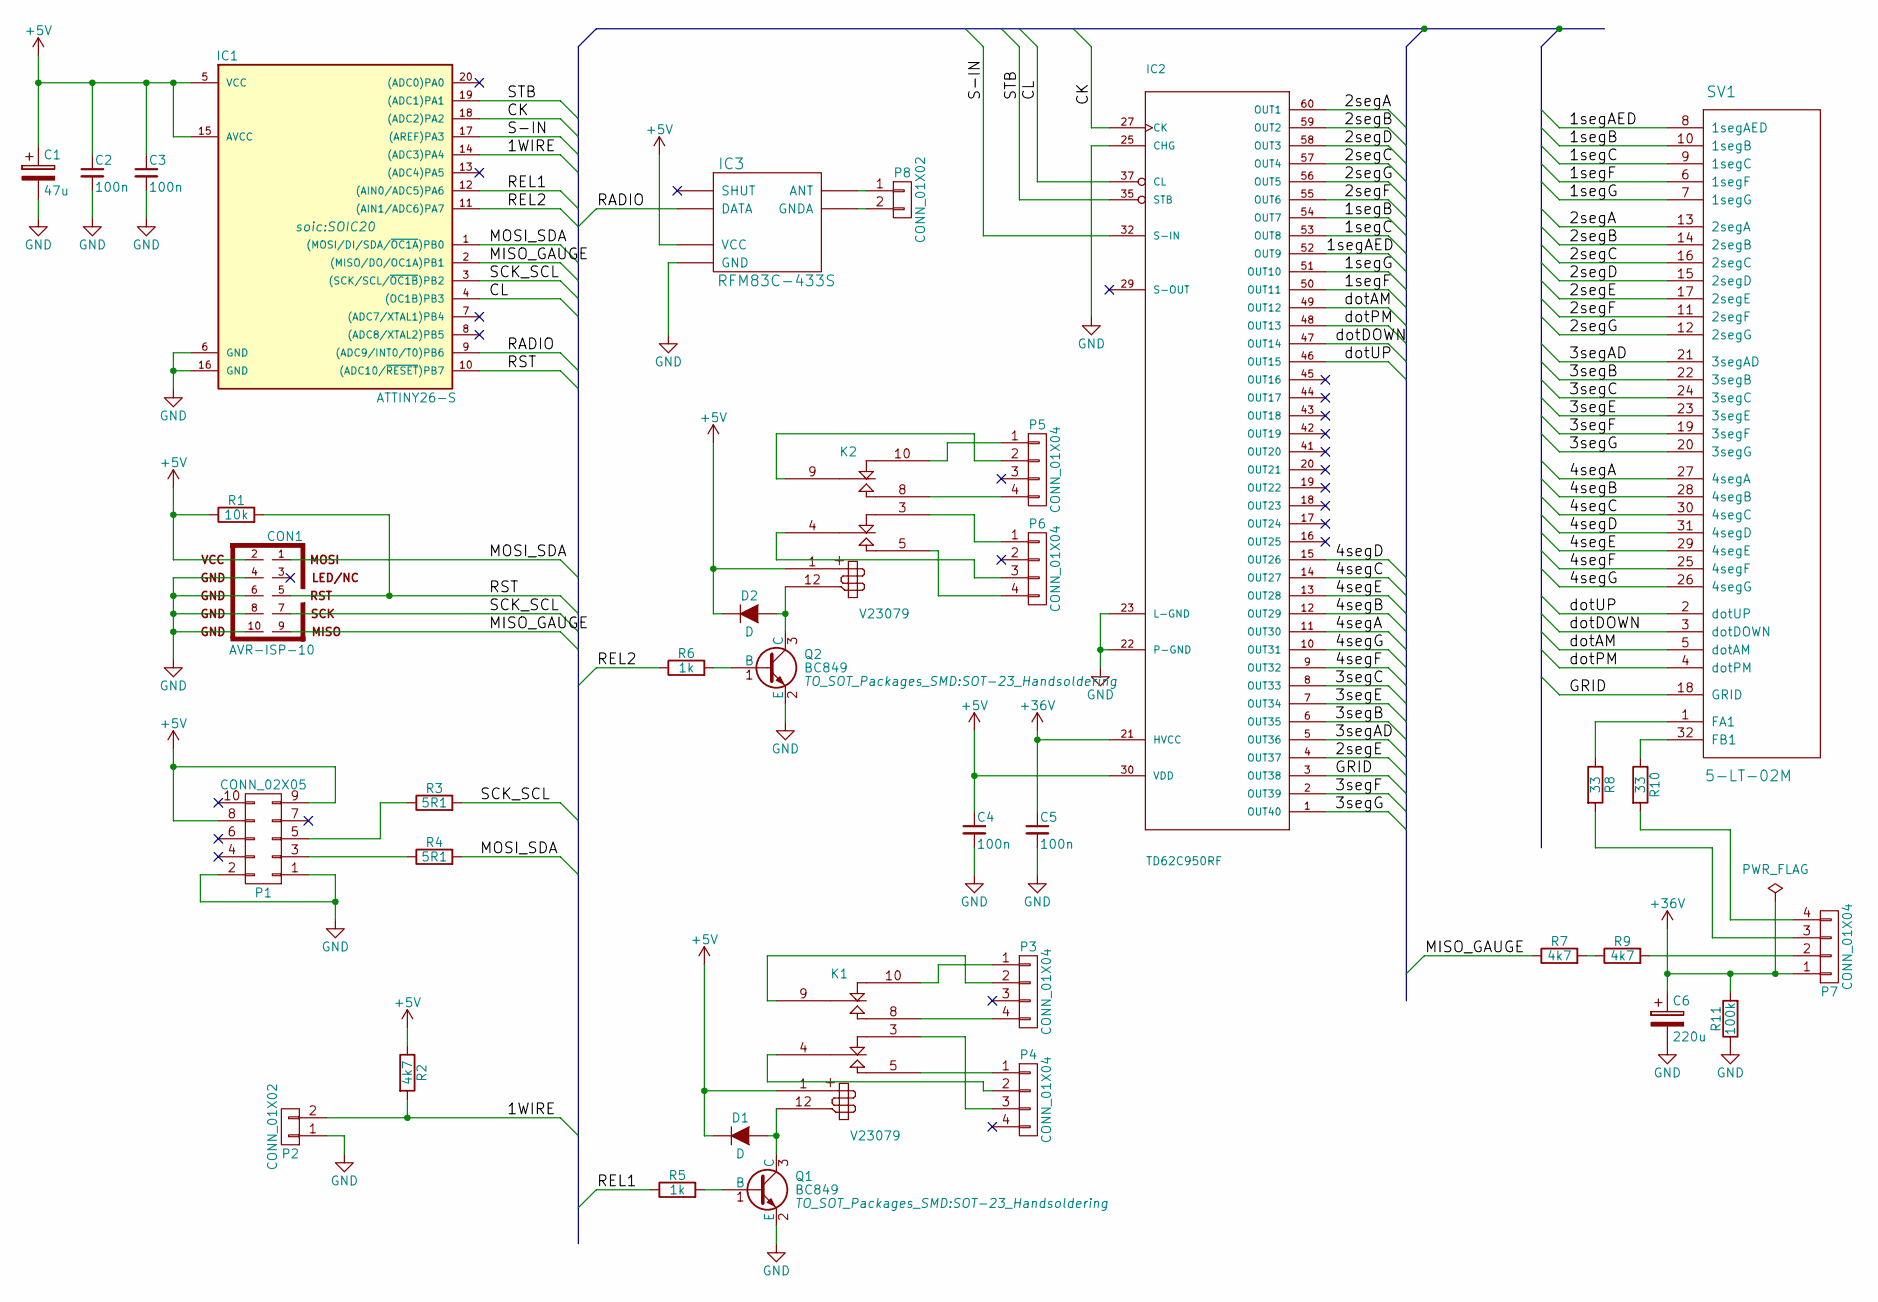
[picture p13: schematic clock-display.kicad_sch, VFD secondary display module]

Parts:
C1: 47u; c_elec_8x10
C2, C3, C4, C5: 100n; C_1206_HandSoldering
C6: 220u; c_elec_10x10
CON1: AVR-ISP-10; Pin_Header_Straight_2x05_Pitch2.54mm
D1, D2: D; SMA_Handsoldering
IC1: ATTINY26-S; SOIC20
IC2: TD62C950RF; TD62C950RF-SSOP60-P-0.65A
IC3: RFM83C-433S; RFM83C_standard
K1, K2: V23079; V23098-SMT-long
P1: CONN_02X05; Pin_Header_Straight_2x05_Pitch2.54mm
P2, P8: CONN_01X02; Pin_Header_Straight_1x02_Pitch2.54mm
P3, P4, P7: CONN_01X04; 0-188275-4_SMD_4-pin_female
P5, P6: CONN_01X04; 0-215464-4_TH_4-pin_male
Q1, Q2: BC849; SOT-23_Handsoldering
R1: 10k; R_1206_HandSoldering
R2, R7, R9: 4k7; R_1206_HandSoldering
R3, R4: 5R1; R_1206_HandSoldering
R5, R6: 1k; R_1206_HandSoldering
R8, R10: 33; Resistor_Horizontal_RM15mm
R11: 100k; R_1206_HandSoldering
SV1: 5-LT-02M; futaba-vfd-5-LT-02

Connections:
+5V: C1.1, C2.1, C3.1, C4.1, CON1.2, D1.1 (K), D2.1 (K), IC1.5 (VCC), IC1.15 (AVCC), IC2.30 (VDD), IC2.31 (VDD), IC3.4 (VCC), K1.1 (+), K2.1 (+), P1.8, P1.9, R1.1, R2.1
+36V: C5.1, C6.1, IC2.21 (HVCC), IC2.40 (HVCC), P7.1, R11.2
/1WIRE: IC1.14 ((ADC3)PA4), P2.2, R2.2
/1segAED: IC2.52 (OUT9), SV1.8 (1segAED)
/1segB: IC2.54 (OUT7), SV1.10 (1segB)
/1segC: IC2.53 (OUT8), SV1.9 (1segC)
/1segF: IC2.50 (OUT11), SV1.6 (1segF)
/1segG: IC2.51 (OUT10), SV1.7 (1segG)
/2segA: IC2.60 (OUT1), SV1.13 (2segA)
/2segB: IC2.59 (OUT2), SV1.14 (2segB)
/2segC: IC2.57 (OUT4), SV1.16 (2segC)
/2segD: IC2.58 (OUT3), SV1.15 (2segD)
/2segE: IC2.4 (OUT37), SV1.17 (2segE)
/2segF: IC2.55 (OUT6), SV1.11 (2segF)
/2segG: IC2.56 (OUT5), SV1.12 (2segG)
/3segAD: IC2.5 (OUT36), SV1.21 (3segAD)
/3segB: IC2.6 (OUT35), SV1.22 (3segB)
/3segC: IC2.8 (OUT33), SV1.24 (3segC)
/3segE: IC2.7 (OUT34), SV1.23 (3segE)
/3segF: IC2.2 (OUT39), SV1.19 (3segF)
/3segG: IC2.1 (OUT40), SV1.20 (3segG)
/4segA: IC2.11 (OUT30), SV1.27 (4segA)
/4segB: IC2.12 (OUT29), SV1.28 (4segB)
/4segC: IC2.14 (OUT27), SV1.30 (4segC)
/4segD: IC2.15 (OUT26), SV1.31 (4segD)
/4segE: IC2.13 (OUT28), SV1.29 (4segE)
/4segF: IC2.9 (OUT32), SV1.25 (4segF)
/4segG: IC2.10 (OUT31), SV1.26 (4segG)
/CK: IC1.18 ((ADC2)PA2), IC2.27 (CK)
/CL: IC1.4 ((OC1B)PB3), IC2.37 (CL)
/GRID: IC2.3 (OUT38), SV1.18 (GRID)
/MISO_GAUGE: CON1.9, IC1.2 ((MISO/DO/OC1A)PB1), R7.1
/MOSI_SDA: CON1.1, IC1.1 ((MOSI/DI/SDA/~OC1A)PB0), R4.2
/RADIO: IC1.9 ((ADC9/INT0/T0)PB6), IC3.5 (DATA)
/REL1: IC1.12 ((AIN0/ADC5)PA6), R5.1
/REL2: IC1.11 ((AIN1/ADC6)PA7), R6.1
/RST: CON1.5, IC1.10 ((ADC10/~RESET)PB7), R1.2
/S-IN: IC1.17 ((AREF)PA3), IC2.32 (S-IN)
/SCK_SCL: CON1.7, IC1.3 ((SCK/SCL/~OC1B)PB2), R3.2
/STB: IC1.19 ((ADC1)PA1), IC2.35 (STB)
/dotAM: IC2.49 (OUT12), SV1.5 (dotAM)
/dotDOWN: IC2.47 (OUT14), SV1.3 (dotDOWN)
/dotPM: IC2.48 (OUT13), SV1.4 (dotPM)
/dotUP: IC2.46 (OUT15), SV1.2 (dotUP)
GND: C1.2, C2.2, C3.2, C4.2, C5.2, C6.2, CON1.4, CON1.6, CON1.8, CON1.10, IC1.6 (GND), IC1.16 (GND), IC2.22 (P-GND), IC2.23 (L-GND), IC2.25 (CHG), IC2.38 (L-GND), IC2.39 (P-GND), IC3.6 (GND), P1.1, P1.2, P2.1, Q1.2 (E), Q2.2 (E), R11.1
unnamed: D1.2 (A), K1.12 (-), Q1.3 (C)
unnamed: D2.2 (A), K2.12 (-), Q2.3 (C)
unnamed: IC3.1 (ANT), P8.1
unnamed: IC3.2 (GNDA), P8.2
unnamed: K1.4 (C1), P4.2
unnamed: K1.9 (C2), P3.2
unnamed: K1.3 (R1), P4.3
unnamed: K1.10 (R2), P3.1
unnamed: K1.5 (T1), P4.1
unnamed: K1.8 (T2), P3.4
unnamed: K2.4 (C1), P6.3
unnamed: K2.9 (C2), P5.2
unnamed: K2.3 (R1), P6.1
unnamed: K2.10 (R2), P5.1
unnamed: K2.5 (T1), P6.4
unnamed: K2.8 (T2), P5.4
unnamed: P1.3, R4.1
unnamed: P1.5, R3.1
unnamed: P7.2, R9.2
unnamed: P7.3, R8.2
unnamed: P7.4, R10.2
unnamed: Q1.1 (B), R5.2
unnamed: Q2.1 (B), R6.2
unnamed: R7.2, R9.1
unnamed: R8.1, SV1.1 (FA1)
unnamed: R10.1, SV1.32 (FB1)

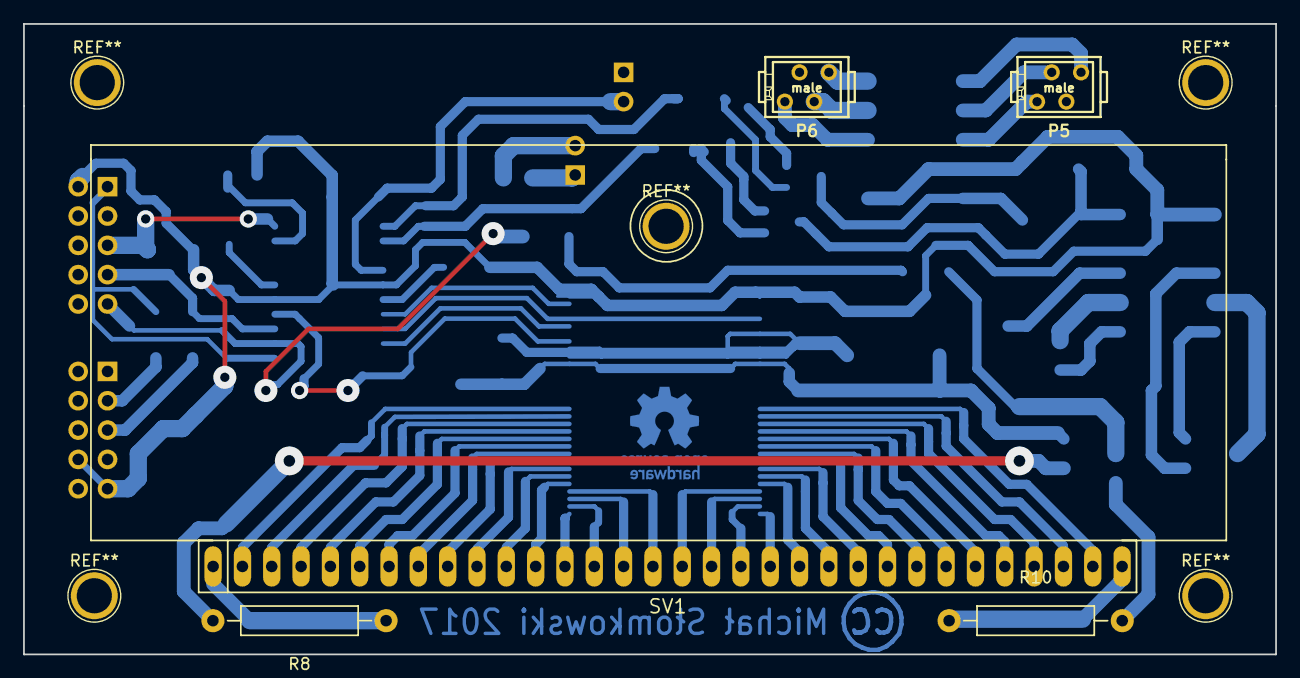
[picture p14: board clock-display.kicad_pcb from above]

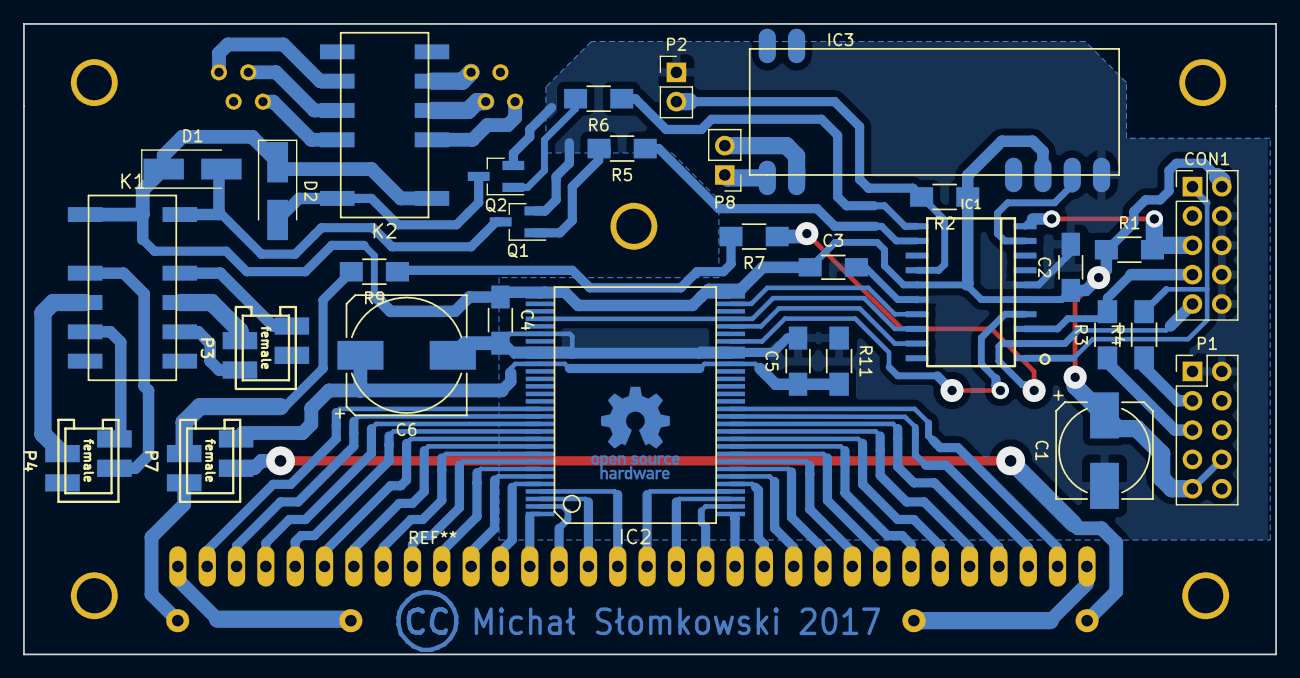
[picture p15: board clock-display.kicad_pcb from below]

Board: 2 copper layers, 108.5 x 54.6 mm, 36 parts (31 on the bottom side), 71 nets.

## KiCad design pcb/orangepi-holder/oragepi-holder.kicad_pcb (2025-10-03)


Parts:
C1, C3, C5, C6, C8: 100n; C_1206_HandSoldering
C2, C4: 47u; CP_Radial_D7.5mm_P2.50mm
C7: 1000u; CP_Axial_L30.0mm_D10.0mm_P35.00mm_Horizontal
J1, J2: Conn_01x02_Male; Pin_Header_Angled_1x02_Pitch2.54mm
J3, J4, J5, J6: Conn_02x05_Odd_Even; IDC-Header_2x05_P2.54mm_Vertical
J7: Conn_02x02_Odd_Even; 0-215464-4_TH_4-pin_male
LA1, LA2: Lamp; Pin_Header_Straight_1x02_Pitch2.00mm
Q1, Q2: BD227; TO-126_Vertical
Q3, Q4: BSN10A; TO-92_Molded_Wide_Oval
R1, R2, R3, R4: 1k; R_1206_HandSoldering
R5, R6: 470; R_1206_HandSoldering
R7, R10: 4k7; R_1206_HandSoldering
R8, R12: 27; R_Axial_DIN0414_L11.9mm_D4.5mm_P15.24mm_Horizontal
R9, R11: 3k6; R_Axial_DIN0411_L9.9mm_D3.6mm_P15.24mm_Horizontal
R13, R14: 10k; R_Axial_DIN0411_L9.9mm_D3.6mm_P15.24mm_Horizontal
R15: 4k7; R_Axial_DIN0411_L9.9mm_D3.6mm_P15.24mm_Horizontal
RV1, RV2: 1k; SP5-2
SW1: SW_SPST; SPDT
SW2: SW_Push; SPDT
SW3: SW_DPDT_x2; APEM_5246
U1: orange_pi_zero; orangepi-zero
U2: DAC5573; TSSOP-16_4.4x5mm_Pitch0.65mm

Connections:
+3V3: C8.2, J3.10, J4.10, J5.10, J6.10, J7.4, Q1.1 (E), Q2.1 (E), Q3.2 (G), Q4.2 (G), R13.2, R14.2, R15.1
+5V: C1.2, C2.1, C7.1, J3.8, J3.9, J4.8, J4.9, J5.8, J5.9, J6.8, J6.9, R9.2, R11.2, SW1.2 (B), U2.3 (VREFH), U2.4 (VDD), U2.12 (IOVDD), U2.13 (A0), U2.14 (A1)
BUTTON: R15.2, SW2.2, U1.107 (PWM1_/_PA06)
GND: C1.1, C2.2, C3.2, C4.2, C5.1, C6.1, C7.2, C8.1, J1.2, J2.2, J3.1, J3.2, J4.1, J4.2, J5.1, J5.2, J6.1, J6.2, J7.2, R5.2, R6.2, R7.1, R8.1, R10.1, R12.1, SW2.1, U1.106 (GND), U1.109 (GND), U1.114 (GND), U1.120 (GND), U1.125 (GND), U2.5 (VREFL), U2.6 (GND), U2.15 (A2), U2.16 (A3)
LAMP1: Q1.3 (B), R7.2, U1.122 (UART2_RTS_/_PA02)
LAMP2: Q2.3 (B), R10.2, U1.116 (TWI1-SDA_/_PA19)
unnamed: C5.2, J1.1, R5.1, RV1.1
unnamed: C6.2, J2.1, R6.1, RV2.1
unnamed: J7.1, SW3.1 (A)
unnamed: J7.3, SW3.4 (A)
unnamed: LA1.2 (+), Q1.2 (C)
unnamed: LA1.1 (-), R8.2
unnamed: LA2.2 (+), Q2.2 (C)
unnamed: LA2.1 (-), R12.2
unnamed: Q3.3 (S), R13.1, SW3.5 (B)
unnamed: Q4.3 (S), R14.1, SW3.2 (B)
unnamed: R1.2, R3.1
unnamed: R2.2, R4.1
unnamed: R3.2, RV1.2, RV1.3
unnamed: R4.2, RV2.2, RV2.3
unnamed: C3.1, C4.1, SW1.1 (A), U1.102 (5V), U1.104 (5V)
unnamed: R1.1, U2.1 (VoutA)
unnamed: R2.1, U2.2 (VoutB)
OPI_SCL: SW3.6 (C), U1.105 (TWI0_SCK_/_PA11)
OPI_SDA: SW3.3 (C), U1.103 (TWI0_SDA_/_PA12)
SCL: J3.5, J4.5, J5.5, J6.5, Q3.1 (D), R9.1, U2.10 (SCL)
SDA: J3.3, J4.3, J5.3, J6.3, Q4.1 (D), R11.1, U2.11 (SDA)



Board: 2 copper layers, 96.5 x 64.8 mm, 43 parts (15 on the bottom side), 27 nets.

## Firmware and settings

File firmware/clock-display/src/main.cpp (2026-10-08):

#include "display.hpp"
#include "relay.hpp"
#include "receiver433.hpp"
#include "i2c-slave.hpp"
#include "protocol.hpp"
#include "light-sensor.hpp"

#include <avr/io.h>
#include <avr/wdt.h>
#include <avr/interrupt.h>
#include <util/crc16.h>

constexpr bool WATCHDOG_ENABLE = true;
constexpr bool VERIFY_INPUT_I2C_COMMANDS_CRC8 = true;


using namespace octoglow::vfd_clock;
using namespace octoglow::vfd_clock::protocol;

static auto currentCommand = Command::NONE;

/**
 * Set by ENTER_BOOTLOADER. The main loop stops feeding the watchdog, so the MCU resets
 * within WDTO_250MS. The I2C reply is still served in the meantime. The reset vector
 * is patched by the bootloader, so every reset starts the bootloader, which waits ~1 s for the host.
 */
static bool bootloaderRequested = false;

/**
 *
 * @param dataPayloadLength We include the command byte and the following payload.
 * Payload length can be 0, in this case only the command byte is taken to the calculation.
 * @return if CRC calculated locally matches the CRC sent via I2C
 */
static bool checkCrc8(const uint8_t dataPayloadLength) {
    if constexpr (!VERIFY_INPUT_I2C_COMMANDS_CRC8) {
        return true;
    }

    uint8_t calculatedCrcValue = 0;
    for (uint8_t i = 1; i < dataPayloadLength + 2; ++i) {
        calculatedCrcValue = _crc8_ccitt_update(calculatedCrcValue, i2c_wrbuf[i]);
    }
    return i2c_wrbuf[0] == calculatedCrcValue;
}

// __attribute__((optimize("O3"), hot))
static inline void setCrcForSimpleCommand() {
    i2c_rdbuf[0] = _crc8_ccitt_update(0, i2c_rdbuf[1]);
    i2c_reply_done(2);
}

static void setCrcForComplexCommand(const uint8_t payloadLength) {
    uint8_t crcValue = 0;
    for (uint8_t i = 1; i < payloadLength + 2; ++i) {
        crcValue = _crc8_ccitt_update(crcValue, i2c_rdbuf[i]);
    }
    i2c_rdbuf[0] = crcValue;
    i2c_reply_done(payloadLength + 2);
}

static void processI2cReadCommands() {
    if (!i2c_reply_ready()) {
        return;
    }

    using namespace octoglow::vfd_clock::protocol;

    i2c_rdbuf[1] = i2c_wrbuf[1];

    static_assert(sizeof(WeatherSensorState) + 2 <= sizeof(i2c_rdbuf));

    switch (currentCommand) {
        case Command::GET_WEATHER_SENSOR_STATE: {
            for (uint8_t i = sizeof(WeatherSensorState) + 1; i != 1; --i) {
                i2c_rdbuf[i] = reinterpret_cast<uint8_t *>(&receiver433::currentWeatherSensorState)[i - 2];
            }
            receiver433::currentWeatherSensorState.flags |= ALREADY_READ_FLAG;
            setCrcForComplexCommand(sizeof(WeatherSensorState));
            break;
        }
        case Command::GET_LIGHT_SENSOR_VALUE: {
            const uint16_t measurement = lightsensor::getMeasurement();
            i2c_rdbuf[2] = 0xff & measurement;
            i2c_rdbuf[3] = 0xff & (measurement >> 8);
            setCrcForComplexCommand(2);
            break;
        }
        case Command::GET_RELAY_STATE: {
            const auto [relay1enabled, relay2enabled] = relay::queryRelayState();
            i2c_rdbuf[2] = relay1enabled | (relay2enabled << 1);
            setCrcForComplexCommand(1);
            break;
        }
        case Command::SET_BRIGHTNESS:
        case Command::SET_RELAY:
        case Command::SET_DISPLAY_CONTENT:
        case Command::ENTER_BOOTLOADER: {
            setCrcForSimpleCommand();
            break;
        }
        default:
            break;
    }

    currentCommand = Command::NONE;
}

static void processI2cWriteCommands() {
    if (!i2c_message_ready()) {
        return;
    }

    static_assert(sizeof(DisplayContent) + 2 <= sizeof(i2c_wrbuf));
    static_assert(sizeof(RelayState) + 2 <= sizeof(i2c_wrbuf));
    static_assert(sizeof(BOOTLOADER_MAGIC) + 2 <= sizeof(i2c_wrbuf));

    switch (const auto incomingCommand = static_cast<Command>(i2c_wrbuf[1])) {
        case Command::SET_DISPLAY_CONTENT: {
            if (!checkCrc8(sizeof(DisplayContent))) {
                break;
            }
            const auto *dc = reinterpret_cast<volatile DisplayContent *>(&i2c_wrbuf[2]);
            display::setDots(dc->dotState, false);
            display::setAllCharacters(dc->characters);
            currentCommand = Command::SET_DISPLAY_CONTENT;
        }
        break;
        case Command::SET_RELAY: {
            if (!checkCrc8(1)) {
                break;
            }
            relay::setState(relay::Relay::RELAY_1, (1 << static_cast<int>(relay::Relay::RELAY_1)) & i2c_wrbuf[2]);
            relay::setState(relay::Relay::RELAY_2, (1 << static_cast<int>(relay::Relay::RELAY_2)) & i2c_wrbuf[2]);
            currentCommand = Command::SET_RELAY;
        }
        break;
        case Command::SET_BRIGHTNESS:
            if (!checkCrc8(1)) {
                break;
            }
            display::setBrightness(i2c_wrbuf[2]);
            currentCommand = Command::SET_BRIGHTNESS;
            break;
        case Command::ENTER_BOOTLOADER: {
            if (!checkCrc8(sizeof(BOOTLOADER_MAGIC))) {
                break;
            }
            bool magicMatches = true;
            for (uint8_t i = 0; i != sizeof(BOOTLOADER_MAGIC); ++i) {
                magicMatches &= i2c_wrbuf[2 + i] == BOOTLOADER_MAGIC[i];
            }
            if (!magicMatches) {
                break;
            }
            display::setAllCharacters("____");
            bootloaderRequested = true;
            currentCommand = Command::ENTER_BOOTLOADER;
        }
        break;
        case Command::GET_WEATHER_SENSOR_STATE:
        case Command::GET_LIGHT_SENSOR_VALUE:
        case Command::GET_RELAY_STATE:
            if (!checkCrc8(0)) {
                break;
            }
            currentCommand = incomingCommand;
            break;
        default:
            currentCommand = Command::NONE;
            break;
    }

    i2c_message_done();
}

[[noreturn]] int main() {
    // pull-up all unused pins
    PORTA |= _BV(PA0) | _BV(PA5);
    PORTB |= _BV(PB1) | _BV(PB4) | _BV(PB5) | _BV(PB7);

    i2c_initialize();
    display::init();
    relay::init();
    receiver433::init();
    lightsensor::init();

    if (WATCHDOG_ENABLE) {
        wdt_enable(WDTO_250MS);
    }

    sei();

    while (true) {
        receiver433::pool();

        processI2cReadCommands();
        processI2cWriteCommands();

        if (bootloaderRequested) {
            // stop feeding the watchdog; enable it if WATCHDOG_ENABLE = false
            if (!(WDTCR & _BV(WDE))) {
                wdt_enable(WDTO_250MS);
            }
        } else if (WATCHDOG_ENABLE) {
            wdt_reset();
        }
    }
}

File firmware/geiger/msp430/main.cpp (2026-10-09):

#include "main.hpp"
#include "magiceye.hpp"
#include "inverter.hpp"
#include "i2c-slave.hpp"
#include "geiger-counter.hpp"

#include <msp430.h>
#include <iomacros.h>

using namespace octoglow::geiger;


namespace octoglow::geiger {
    volatile bool timerTicked = false;
}

/**
 * Time for the host to read the reply to ENTER_BOOTLOADER, in ticks.
 */
constexpr uint8_t BOOTLOADER_ENTRY_DELAY_TICKS = TICK_TIMER_FREQ / 10;

/**
 * Writing WDTCTL without the password resets the MCU immediately, the bootloader starts.
 */
[[noreturn]] static void resetIntoBootloader() {
    inverter::setPwmOutputsToSafeState();
    WDTCTL = 0;
    while (true) {
    }
}

static inline void configureClockSystem() {
    BCSCTL3 = LFXT1S_3 | XCAP_0;

    do {
        IFG1 &= ~OFIFG;
        volatile uint16_t i = 250;
        while (--i) {
        }
    } while (IFG1 & OFIFG);

    BCSCTL2 = SELM_0 | DIVM_0 | SELS | DIVS_0;

    i2c::setClockToHigh();
}

__interrupt_vec(TRAPINT_VECTOR) [[noreturn]] void trapHandler() {
    inverter::setPwmOutputsToSafeState();

    while (true) {
        __no_operation();
    }
}

[[noreturn]] int main() {
    inverter::setPwmOutputsToSafeState();

    WDTCTL = WDTPW | WDTHOLD;

    P1DIR |= BIT0;
    P2DIR |= BIT0 + BIT7; // configure unused pins as output

    volatile uint16_t i = 0xfff0;
    do i--;
    while (i != 0);

    configureClockSystem();

    magiceye::init();
    inverter::init();
    i2c::init();
    geiger_counter::init();

    WDTCTL = WDTPW + WDTSSEL + WDTIS0;

    __nop();
    __enable_interrupt();
    __nop();

    uint8_t bootloaderEntryTicks = 0;

    while (true) {
        if (timerTicked) {
            P1OUT |= BIT0; // pin no 2

            timerTicked = false;

            // the code below is executed at the frequency TICK_TIMER_FREQ = 100 Hz

            inverter::tick();
            magiceye::tick();
            geiger_counter::tick();

            if (i2c::bootloaderRequested and ++bootloaderEntryTicks == BOOTLOADER_ENTRY_DELAY_TICKS) {
                resetIntoBootloader();
            }

            P1OUT &= ~BIT0;
        }
        i2c::processDataIfAvailable();

        WDTCTL = WDTPW + WDTCNTCL;
    }
}

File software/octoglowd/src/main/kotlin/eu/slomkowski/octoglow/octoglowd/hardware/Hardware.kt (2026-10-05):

package eu.slomkowski.octoglow.octoglowd.hardware

import eu.slomkowski.octoglow.octoglowd.Config
import io.github.oshai.kotlinlogging.KotlinLogging
import io.helins.linux.i2c.I2CBuffer
import io.helins.linux.i2c.I2CBus
import io.helins.linux.i2c.I2CFunctionality
import kotlinx.coroutines.*
import kotlinx.coroutines.sync.Mutex
import kotlinx.coroutines.sync.withLock
import java.io.IOException
import java.util.concurrent.Executors
import kotlin.time.Duration
import kotlin.time.ExperimentalTime

interface Hardware : AutoCloseable {

    val clockDisplay: ClockDisplay
    val frontDisplay: FrontDisplay
    val geiger: Geiger
    val dac: Dac
    val scd40: Scd40
    val bme280: Bme280

    override fun close()

    suspend fun setBrightness(brightness: Int)

    suspend fun doWrite(i2cAddress: Int, writeData: IntArray)

    suspend fun doTransaction(
        i2cAddress: Int,
        writeData: IntArray,
        bytesToRead: Int,
        delayBetweenWriteAndRead: Duration,
    ): IntArray
}

@ExperimentalTime
class HardwareReal(
    private val bus: I2CBus,
) : Hardware {

    enum class Errno(
        val code: Int,
        val message: String
    ) {
        EAGAIN(11, "Resource temporarily unavailable  (same code as EWOULDBLOCK)"),
        EBADMSG(74, "Bad message"),
        EBUSY(16, "Device or resource busy"),
        EIN(22, "Invalid argument"),
        EIO(5, "Input/output error"),
        ENODEV(19, "No such device"),
        ENOMEM(12, "Cannot allocate memory"),
        ENXIO(6, "No such device or address"),
        EOPNOTSUPP(95, "Operation not supported"),
        EPROTO(71, "Protocol error"),
        ESHUTDOWN(108, "Cannot send after transport endpoint shutdown"),
        ETIMEDOUT(110, "Connection timed out")
    }

    /**
     * All bus access is confined to this single thread rather than hopping onto [Dispatchers.IO] per
     * operation. The I2C calls are blocking JNA syscalls, so they need a thread of their own anyway,
     * and confining them means the write/wait/read sequence never gets rescheduled onto a different
     * worker - which is what lets [waitBetweenWriteAndRead] be an ordinary sleep.
     */
    private val busContext = Executors.newSingleThreadExecutor { Thread(it, "i2c") }.asCoroutineDispatcher()

    private val busMutex = Mutex()
    private val writeI2cBuffer = I2CBuffer(I2C_BUFFER_MAX_SIZE)
    private val readI2cBuffer = I2CBuffer(I2C_BUFFER_MAX_SIZE)

    companion object {
        private val logger = KotlinLogging.logger {}

        private const val I2C_BUFFER_MAX_SIZE = 500

        private val exceptionRegex = Regex("errno (\\d+)")

        fun handleI2cException(baseException: Exception): Exception = exceptionRegex
            .find(baseException.message ?: "")
            ?.let { matchResult ->
                val errno = matchResult.groupValues[1].toInt()

                val knownErrno = Errno.entries.firstOrNull { errno == it.code }

                IOException(
                    "native I2C transaction error: " + when (knownErrno) {
                        null -> "errno $errno"
                        else -> "$knownErrno: ${knownErrno.message}"
                    }, baseException
                )
            } ?: baseException
    }

    override val clockDisplay = ClockDisplay(this)

    override val frontDisplay = FrontDisplayReal(this)

    override val geiger = Geiger(this)

    override val dac = Dac(this)

    override val scd40 = Scd40(this)

    override val bme280 = Bme280(this)

    private val allDevices = listOf(
        frontDisplay,
        clockDisplay,
        geiger,
        dac,
        scd40,
        bme280,
    )

    private val brightnessDevices = allDevices.filterIsInstance<HasBrightness>()

    init {
        require(bus.functionalities.can(I2CFunctionality.TRANSACTIONS)) { "I2C bus requires transaction support" }
        require(bus.functionalities.can(I2CFunctionality.READ_BYTE)) { "I2C requires read byte support" }

        try {
            runBlocking {
                frontDisplay.apply {
                    initDevice()
                    clear()
                    setStaticText(0, "Initializing...")
                }

                allDevices.minus(frontDisplay).forEach { launch { it.initDevice() } }
            }
        } catch (e: Exception) {
            logger.error(e) { "Error during hardware initialization" }
        }
    }

    constructor(config: Config) : this(I2CBus(config.i2cBus))

    override suspend fun setBrightness(brightness: Int): Unit = coroutineScope {
        brightnessDevices.forEach { launch { it.setBrightness(brightness) } }
    }

    override fun close() {
        runBlocking {
            for (device in allDevices) {
                try {
                    device.closeDevice()
                } catch (e: Exception) {
                    logger.error(e) { "Failed to close device $device" }
                }
            }
        }
        busContext.close()
    }

    private fun fillWriteBuffer(writeArray: IntArray) {
        require(writeArray.isNotEmpty()) { "array with data do write cannot be empty" }
        require(writeArray.size <= writeI2cBuffer.length) { "write array size ${writeArray.size} exceeds buffer length ${writeI2cBuffer.length}" }
        writeArray.forEachIndexed { index, value -> writeI2cBuffer[index] = value }
    }

    /**
     * The datasheet gap between writing a command and reading its answer. It is a few milliseconds at
     * most and it is spent holding [busMutex], so a coroutine `delay` here would hand the thread to
     * another task and only resume once the scheduler got round to it - on a loaded Cortex-A7 a
     * nominal 1 ms routinely became 10 ms or more, with the whole bus locked throughout. On the
     * confined bus thread a plain sleep is both shorter and more predictable.
     */
    private fun waitBetweenWriteAndRead(duration: Duration) {
        val millis = duration.inWholeMilliseconds
        if (millis > 0) {
            Thread.sleep(millis)
        }
    }

    override suspend fun doWrite(i2cAddress: Int, writeData: IntArray) = withContext(busContext) {
        try {
            busMutex.withLock {
                fillWriteBuffer(writeData)
                bus.selectSlave(i2cAddress)
                bus.write(writeI2cBuffer, writeData.size)
            }
        } catch (e: Exception) {
            throw handleI2cException(e)
        }
    }

    override suspend fun doTransaction(
        i2cAddress: Int,
        writeData: IntArray,
        bytesToRead: Int,
        delayBetweenWriteAndRead: Duration,
    ): IntArray {
        require(bytesToRead in 1..100)
        val numberOfTries = 3

        val resultArray = IntArray(bytesToRead)
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

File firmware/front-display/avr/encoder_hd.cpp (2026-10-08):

#include "encoder.hpp"
#include "clock.hpp"

#include "main.hpp"

#include <avr/interrupt.h>
#include <avr/pgmspace.h>
#include <util/atomic.h>

#include "display.hpp"

#define ENC_PORT D
#define ENC_A_PIN 1
#define ENC_B_PIN 2
#define ENC_BTN_PIN 3

/*
 The encoder: PEC11H-4120F-S0020.
 Datasheet: https://www.bourns.com/docs/product-datasheets/pec11h.pdf
 20 pulses, 20 detents, suggested filter circuit from the datasheet added.
 Datasheet says it is a half-step encoder according to the picture, but it is a full-step encoder in reality.
 Detent is on value 11.

 turning CW:
 **          **
 11 10 00 01 11
 */

using namespace octoglow::front_display::encoder;

constexpr uint8_t DEBOUNCE_ITERATIONS = 20;
constexpr uint16_t TICK_FREQUENCY = 1000; // Hz

void octoglow::front_display::encoder::init() {
    // enable pull-up for the button, not for the encoder
    PORT(ENC_PORT) |= _BV(ENC_BTN_PIN);

    PCICR |= _BV(PCIE2);
    PCMSK2 |= _BV(PCINT18) | _BV(PCINT17);

    TCCR0A = _BV(WGM01);
    TCCR0B = _BV(CS01) | _BV(CS00); // f_cpu / 64
    OCR0A = (F_CPU / 64 / TICK_FREQUENCY) - 1;
    TIMSK0 |= _BV(OCIE0A);
}

constexpr uint8_t DIR_NONE = 0x0;
constexpr uint8_t DIR_CW = 0x10;
constexpr uint8_t DIR_CCW = 0x20;

constexpr uint8_t R_START = 0x0;
constexpr uint8_t R_CW_FINAL = 0x1;
constexpr uint8_t R_CW_BEGIN = 0x2;
constexpr uint8_t R_CW_NEXT = 0x3;
constexpr uint8_t R_CCW_BEGIN = 0x4;
constexpr uint8_t R_CCW_FINAL = 0x5;
constexpr uint8_t R_CCW_NEXT = 0x6;

// encoder code taken from https://github.com/buxtronix/arduino/blob/master/libraries/Rotary/Rotary.cpp
static const uint8_t ttable[7][4] PROGMEM = {
    // R_START
    {R_START, R_CW_BEGIN, R_CCW_BEGIN, R_START},

    // R_CW_FINAL
    {R_CW_NEXT, R_START, R_CW_FINAL, R_START | DIR_CW},

    // R_CW_BEGIN
    {R_CW_NEXT, R_CW_BEGIN, R_START, R_START},

    // R_CW_NEXT
    {R_CW_NEXT, R_CW_BEGIN, R_CW_FINAL, R_START},

    // R_CCW_BEGIN
    {R_CCW_NEXT, R_START, R_CCW_BEGIN, R_START},

    // R_CCW_FINAL
    {R_CCW_NEXT, R_CCW_FINAL, R_START, R_START | DIR_CCW},

    // R_CCW_NEXT
    {R_CCW_NEXT, R_CCW_FINAL, R_CCW_BEGIN, R_START},
};

static volatile uint8_t state = R_START;

// triggered on every pin change
ISR(PCINT2_vect) {
    const uint8_t pinState = ((PIN(ENC_PORT) & (_BV(ENC_A_PIN) | _BV(ENC_B_PIN))) >> 1) & 0b11;

    state = pgm_read_byte(&ttable[state & 0xf][pinState]);
    const uint8_t result = state & 0x30;

    if (result == DIR_CW) {
        _currentEncoderSteps++;
    } else if (result == DIR_CCW) {
        _currentEncoderSteps--;
    }
}

static volatile bool prevButtonState = false;
static volatile uint8_t currentDebounceIterations = 0;

static volatile uint8_t milliseconds = 0;

uint8_t octoglow::front_display::clock::milliseconds() {
    return ::milliseconds;
}

// triggered every 1 ms
ISR(TIMER0_COMPA_vect) {
    ++milliseconds;

    if (!(PIN(ENC_PORT) & _BV(ENC_BTN_PIN)) and !prevButtonState) {
        ++currentDebounceIterations;

        if (currentDebounceIterations == DEBOUNCE_ITERATIONS) {
            currentDebounceIterations = 0;
            prevButtonState = true;
            _currentButtonState = ButtonState::JUST_PRESSED;
        }
    } else if (PIN(ENC_PORT) & _BV(ENC_BTN_PIN) and prevButtonState) {
        ++currentDebounceIterations;

        if (currentDebounceIterations == DEBOUNCE_ITERATIONS) {
            currentDebounceIterations = 0;
            prevButtonState = false;
            _currentButtonState = ButtonState::JUST_RELEASED;
        }
    } else {
        currentDebounceIterations = 0;
    }
}

int8_t octoglow::front_display::encoder::getValueAndClear() {
    int8_t v;
    ATOMIC_BLOCK(ATOMIC_RESTORESTATE) {
        v = _currentEncoderSteps;
        _currentEncoderSteps = 0;
    }
    return v;
}

ButtonState octoglow::front_display::encoder::getButtonStateAndClear() {
    ButtonState v;
    ATOMIC_BLOCK(ATOMIC_RESTORESTATE) {
        v = _currentButtonState;
        _currentButtonState = ButtonState::NO_CHANGE;
    }
    return v;
}

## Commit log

2016-07-20 Add work in progress board and libraries.
    [vfd-display-front.kicad_pcb, vfd-display-front.sch]
2016-10-16 Board almost done.
    [vfd-display-front.kicad_pcb, vfd-display-front.sch]
2016-10-20 Board beta complete.
    [vfd-display-front.kicad_pcb]
2016-10-22 Make some lines thicker.
    [vfd-display-front.kicad_pcb]
2016-10-28 Update resistor values.
    [vfd-display-front.sch]
2016-11-27 Add correct footprint for PCB. Fix PCB.
    [vfd-display-front.kicad_pcb, vfd-display-front.sch]
2016-11-27 Move files to valid PCB dir.
    [vfd-display-front.kicad_pcb, vfd-display-front.sch]
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2016-12-12 Fix mess with libraries.
    [vfd-display-front.kicad_pcb, vfd-display-front.sch]
2016-12-12 Move display-front to subdir.
    [vfd-display-front.kicad_pcb, vfd-display-front.sch]
2017-01-09 Add clock schematic and some elements.
    [vfd-display-clock.kicad_pcb, vfd-display-clock.sch]
2017-01-12 Add receiver library element. Finish clock board.
    [vfd-display-clock.kicad_pcb, vfd-display-clock.sch]
2017-01-12 Add symbols, clock board complete.
    [vfd-display-clock.kicad_pcb]
2017-01-15 Add stub for clock board firmware.
    Implement displaying numbers on display.
2017-01-16 Add speaker stub, change VFD display code to use frame buffer.
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2017-01-29 Add relay support. Add brightness setting and dot support.
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2017-07-30 Add case sketch.
    [shape.fcstd]
2017-07-30 Add drawing.
    [shape.fcstd]
2017-10-09 Add some libraries for Geiger.
    [geiger.kicad_pcb, geiger.sch, vfd-display-front.sch]
2017-10-15 Add Geiger, transformer models.
    [geiger.sch]
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2017-10-25 Add almost complete Geiger schematic (without connections to MCU).
    [geiger.kicad_pcb, geiger.sch]
2017-10-25 Update schematic numbering.
    [geiger.sch]
2017-11-05 Add board in-process.
    [geiger.kicad_pcb, geiger.sch]
2017-11-10 Further pcb changes.
    [geiger.kicad_pcb, geiger.sch]
2017-11-13 Finish Geiger schematic.
    [geiger.kicad_pcb, geiger.sch]
2017-11-17 Finish Geiger board.
    [geiger.kicad_pcb, geiger.sch]
2017-11-21 Small modifications of Geiger board.
    [geiger.kicad_pcb]
2017-11-27 Update element values on the schematic.
    [geiger.kicad_pcb, geiger.sch]
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2018-01-18 Add support for eye inverter, add fixed ADC and timer subsystem.
    [main.cpp]
2018-01-19 Separate some code in Geiger to common module. Add unit test harness. Create unit test for eye.
    [geiger.sch]
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2018-02-28 Fix I2C slave working.
    [i2c-slave.cpp, i2c-slave_hd.cpp]
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2018-03-04 Move PCB projects to new names.
    [clock-display.kicad_pcb, clock-display.sch, front-display.kicad_pcb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]
2018-03-14 Fix I2C code for clock display.
    [i2c-slave.cpp]
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2018-03-29 Add new libraries for new Geiger board.
    [geiger.sch]
2018-04-09 Add ready schematic and all connections on board.
    [geiger.kicad_pcb, geiger.sch]
2018-04-10 All connections ready.
    [geiger.kicad_pcb, geiger.sch]
2018-04-11 Add every feature on the board. Beta.
    [geiger.kicad_pcb, geiger.sch]
2018-04-11 Final version of geiger board.
    [geiger.kicad_pcb, geiger.sch]
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2018-04-17 Change some element values geiger.
    [geiger.kicad_pcb, geiger.sch]
2018-04-20 Update geiger element values.
    [geiger.kicad_pcb, geiger.sch]
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2018-04-21 Update element values on geiger board.
    [geiger.kicad_pcb, geiger.sch]
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2018-05-25 Fix static display bug, add degree sign.
    [display.cpp]
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2018-10-28 Add OrangePi holder PCB project.
    [oragepi-holder.kicad_pcb, oragepi-holder.sch]
2018-10-31 Add some lib symbols, add all components to schematic.
    [oragepi-holder.sch]
2018-11-09 Add schematic and board some development.
    [oragepi-holder.kicad_pcb, oragepi-holder.sch]
2018-11-17 Finished schematic and pcb for orange pi.
    [oragepi-holder.kicad_pcb, oragepi-holder.sch]
2018-11-18 Final orange pi board.
    [oragepi-holder.kicad_pcb, oragepi-holder.sch]
2018-11-20 Update part values.
    [oragepi-holder.kicad_pcb, oragepi-holder.sch]
2018-11-29 Update all Kicad files to Kicad 5.
    [clock-display.sch, front-display.sch, geiger.kicad_pcb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]
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2019-02-07 Fix I2C geiger bug. Change master clock to DCO, set crystal oscillator to SMCLK.
    [i2c-slave.cpp, main.cpp]
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2019-03-03 Add ticking fix - use 8MHz normally, switch to 16 MHz for I2C transmission.
    [i2c-slave.cpp, i2c-slave_hd.cpp, main.cpp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]
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2019-03-03 Update values on PCB.
    [geiger.kicad_pcb, geiger.sch]
2019-03-12 Fix assembly plugin, add some exclusions.
2019-03-18 Implement Calendar view.
    [PL.csv]
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2019-04-02 Fix bug with reading negative value from encoder.
2019-04-09 Bump C++ to 17. Fix firmware tests.
    [display.cpp]
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2019-04-24 Move project to directory octoglowd.
    [PL.csv]
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2021-01-28 Add two indicators support.
    [oragepi-holder.sch]
2021-02-01 Fix negative temperature read.
    [Hardware.kt]
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2021-04-12 Implement Fanju sensor weather view. Replace most of Java Time with kotlinx.time. #5
    [Hardware.kt]
2021-07-28 Add I2C error handler.
    [Hardware.kt]
2023-06-19 Fix air quality test.
    [display.cpp]
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2025-05-22 Remove uchuhimo konf library. Bundle stateful4k libr.
    [PL.csv]
2025-06-18 Fix bugs with scrolling text overflow.
    [display.cpp]
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2025-07-02 Fix analog gauge clicking.
    [clock-display.kicad_pcb]
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2025-07-06 Tweak Geiger code, fix tests.
    [protocol.hpp]
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2025-07-15 Add schematic for rotary encoder board.
    [rotary-encoder.kicad_pcb, rotary-encoder.kicad_sch]
2025-07-21 Rotary encoder board.
    [rotary-encoder.kicad_pcb, rotary-encoder.kicad_sch]
2025-07-23 Remove commons-lang3. Add light sensor support in brightness demon. Move Homeassistant package.
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2025-08-12 Revert I2C in main loop change in front-display. Fix encoder and button code.
    [encoder_hd.cpp, i2c-slave.cpp, i2c-slave_hd.cpp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]
2025-10-03 Migrate to KiCAD 9.
    [clock-display.kicad_pcb, clock-display.kicad_sch, front-display.kicad_pcb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]
2025-10-03 Removed old KiCAD files.
    [clock-display.sch, front-display.sch, geiger.sch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]
2025-10-05 Add polling of eye state to monitor changes if ie. board restart.
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2026-02-02 Add drawing of backlight case.
    [backlight.dxf]
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2026-08-18 Add fixes from Claude.
    [Hardware.kt]
2026-09-30 Reduce UI stalls and I/O cost on the device
    Performance pass aimed at the freezes visible on the Orange Pi Zero: the dial
    going unresponsive during redraws, and SD card writes dominating every stored
    sample.
    Front display:
    - All display writes go through a single pending-draw slot served by one
    dedicated job, instead of being awaited inside state machine transitions
    (which poll() awaits in turn). Requests for the same target merge, a new
    target supersedes the old one, and two draws can no longer interleave on
    the bus.
    - Dial polling relaxed to 40 ms (the firmware latches edges and accumulates
    encoder deltas); view cycling and instant-data polling moved to a 250 ms
    slow tick inst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
    [Hardware.kt]
2026-10-05 Bump dependencies
    Gradle 8.12 -> 9.8.0, Kotlin 2.4.20, Shadow 9.6.1, ProGuard 7.10.0,
    SQLDelight 2.4.0, ktor 3.6.0, ktor-mqtt 1.2.0, kotlin-logging 8.0.4,
    coroutines 1.11.0, serialization 1.11.0, datetime 0.8.0, JUnit 6.1.3,
    tinylog 2.8.0 and assorted test libraries. jaxb-runtime stays on 2.3.x
    to match the javax jaxb-api needed by jollyday.
    Adapt the code to the new versions: replace newSingleThreadContext with
    an executor-backed dispatcher, move off deprecated LocalDate accessors,
    use JUnit 6's typed Store.computeIfAbsent, and disable broker persistence
    in MqttDemonTest so it no longer depends on a leftover H2 store file.
    [Hardware.kt]
2026-10-05 Fix stale tests and skip device/credential tests by default
    Update BrightnessDemonTest, NetworkViewTest and IndoorWeatherViewTest to
    the current behaviour (light-sensor brightness table, backlight indicator,
    indoor view layout) and drop a MqttExportableSwitchDemonTest case that
    verified a non-mock logger after a no-op setState.
    Tag tests needing the real device as "hardware" and those calling
    third-party services with test-config.json credentials as "external".
    Both are excluded from `test` unless requested with -PincludeTags.
2026-10-08 Fix receiver update flag blink not being cleared on clock display
    The blink end shared timer1overflowCounter with the 700 ms measurement
    timeout. The counter was not restarted when the blink began, and the
    timeout branch came first in the if-chain, so it could move the state
    back to WAITING_FOR_FIRST_MEASUREMENT without clearing the display flag,
    leaving it lit. The blink could also end immediately if the counter was
    already past 500 ms.
    Time the blink with a dedicated countdown decremented in the Timer1
    overflow ISR and clear the flag before any other state handling. Also
    correct the prescaler and overflow period comments.
2026-10-08 Add I2C bootloader to clock display firmware
    The bootloader is a C++ port of twiboot v3.2 (GPLv2) reduced to
    ATtiny461A with USI, compatible with its protocol and the twiboot host
    tool from multiboot_tool. It lives at 0x0C80-0x0FFF and patches the
    vector table (reset -> bootloader, EE_RDY -> application), since the
    chip has no boot section. After every reset it listens on 0x11 for 1 s.
    Fixes against upstream twiboot's virtual boot section: RJMP offset and
    the jump to the application use word addresses, and the watchdog is
    disabled on startup on ATtiny parts as well.
    The application enters the bootloader on ENTER_BOOTLOADER (0x07, magic
    "BOOT"): it replies, stops feeding the watchdog and re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
    [i2c-slave.cpp, main.cpp, protocol.hpp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]
2026-10-08 Show BOOT on clock display while in bootloader
    The bootloader shows BOOT (8, 0, 0 and T as a mirrored 7) on the VFD,
    the dots blink while the host talks to it, like the activity LED of
    twiboot. The segment pattern is computed at compile time.
    VFD pins, segment and character tables, brightness PWM setup and the
    shift register routine are moved to common/vfd.hpp, shared with the
    application. The application can now display T as well.
    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
2026-10-08 Add ClockDisplay.enterBootloader()
    Sends ENTER_BOOTLOADER with the BOOT magic, the clock display then
    resets into the I2C bootloader. A test checks the request matches the
    one in firmware/clock-display/flash-over-i2c.sh.
2026-10-08 Add firmware upload over I2C to octoglowd
    `octoglowd --burn-firmware clock-display file.hex` uploads the firmware
    instead of running the daemon: it sends ENTER_BOOTLOADER to the
    application, polls the twiboot bootloader, checks the signature and
    size, writes and verifies the image page by page and starts the new
    application. Progress is shown on the front display.
    The USI variant of twiboot NAKs the last byte of a page write, which
    Linux reports as an I/O error, so such errors are ignored and every
    page is verified by reading it back.
    Device names on the command line are the firmware directory names in
    the repository. The command line is parsed with clikt-core; its
    exitProcess has to be se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
2026-10-08 Fix out-of-bounds bugs in front display firmware, extend tests
    Fixes found while extending the tests:
    - writeStaticText() cleared one character after the field, past the
    framebuffer when the field ended at the last position, and didn't
    clear the first character of the field for an empty text.
    - Scrolling wrote the empty column between characters after the window
    when a glyph ended exactly at the end of the window.
    - INVALID_CHARACTER_CODE was 147, past the end of the font, since the
    degree sign was added. It's 146 (empty box) again, a static_assert
    guards it.
    - Control characters read glyphs before the beginning of the font, they
    are shown as invalid characters now.
    - Three- and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
    [display.cpp, i2c-slave.cpp]
2026-10-08 Add I2C bootloader to front display firmware
    The bootloader is a C++ port of twiboot v3.2 (GPLv2) for ATmega88P with
    the TWI peripheral, compatible with its protocol and the twiboot host
    tool, like the one of the clock display. It lives in the boot section
    at 0x1800-0x1FFF (1522 bytes), BOOTRST makes every reset start it, so
    the vector table isn't patched. After every reset it listens on 0x15
    for 1 s, the display shows BOOTLOADER and the upper bar blinks while
    the host talks to it.
    Differences from the USI bootloader of the clock display: TWI ACKs the
    byte which completes a page, the RWW section is enabled again after
    each page write, the timer tick is 10 ms to fit 16 MHz into the 8-bit
    tim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
    [i2c-slave.cpp, main.cpp]
2026-10-08 Add front display firmware upload to octoglowd
    `octoglowd --burn-firmware front-display file.hex` sends
    ENTER_BOOTLOADER to the front display and uploads the firmware through
    its twiboot bootloader at 0x15 (ATmega88P, signature 0x1e930f). The
    application is checked afterwards by reading the end year of
    construction, which has no side effects.
    The front display can't show the progress of its own update, so only
    the result is shown on it.
    TwibootDeviceEmulator emulates both boards: the clock display with USI
    (patched vector table, NAK on the last byte of a page) and the front
    display with TWI (boot section, no NAK).
2026-10-08 Fix front display brightness levels 1 and 2 being almost dark
    The brightness is the moment the CL pin is cleared in the display
    routine, so it depends on the generated code. Since the routine was
    extracted to vfd.hpp, brightness and the upper bar were passed by value
    and the compiler moved the loads: CL was high 0.6% and 10.4% of the time
    at levels 1 and 2 instead of 21.8% and 37.0%, and the refresh rate
    halved. Together with -O2 forced for Release, the auto brightness made
    the display very dark.
    Measured with simavr running the firmware ELF, CL duty cycle at levels
    0-5:
    - before the bootloader, Release (-O3): 0, 21.8, 37.0, 53.9, 73.1, 100%
    - broken: 0, 0.6, 1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
    [vfd.hpp]
2026-10-08 Time front display brightness and scrolling by timers
    The brightness was the moment CL was cleared in the code and the
    scrolling moved every 300 iterations of the main loop, so both depended
    on the generated code: different optimization or a refactoring changed
    the brightness levels, the refresh rate and the scrolling speed.
    Now each character gets a 130 us slot timed by Timer1. At the start of
    the slot, the character shifted in during the previous one is latched
    and CL is set high; Timer1 clears CL (PB2, OC1B) after the on-time of
    the brightness level. A late slot (scrolling step, long I2C interrupt)
    doesn't light a character longer. The scrolling moves every 39 ms,
    counted by the 1 ms tic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
    [display.cpp, encoder_hd.cpp, vfd.hpp]
2026-10-09 Add I2C bootloader to Geiger firmware
    C++ port of twiboot for MSP430G2553 with USCI_B0, compatible with the
    protocol of the clock display and the front display bootloaders.
    MSP430 has no boot section, so the bootloader lives at 0xfc00-0xffff
    with the real vector table and is never erased. The other vectors jump
    through the application's vector table, linked just below it (0xfbe0)
    by msp430/application.ld.in, 3 cycles per interrupt.
    - listens on 0x19 for 1 s after reset, the inverters and the eye
    heaters are switched off meanwhile
    - protocol addresses are relative to the flash start (0xc000); 64-byte
    pages, the 512-byte segment is erased by its first page; the page is
    written after STO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
    [i2c-slave.cpp, main.cpp, protocol.hpp]
2026-10-09 Fix Geiger bootloader sending an extra byte at the start of a read
    UCB0TXIFG of a master read is set together with UCSTTIFG. When START
    was checked just before both flags were set, TXBUF was loaded with the
    byte numbered by the counter of the previous write, e.g. the chip info
    began with CHIP_INFO[4] and the signature was read as 0x3c0025. START
    is now checked again before TXBUF is written.
    [usci-slave.cpp]
2026-10-09 Fix bugs in Geiger firmware found by extended tests
    - STOP after the master read processed the reply as a command again:
    CLEAN_GEIGER_STATE has a valid CRC, so the counters were reset twice
    - reading more than 16 bytes read beyond the I2C buffer
    - a cycle longer than 655 s ended early: cycleLength * 100 overflows
    the 16-bit int of MSP430; counted in seconds now, up to 0xffff s
    - SET_EYE_CONFIGURATION stored an invalid mode (octoglowd fails on it),
    SET_GEIGER_CONFIGURATION with 0 started a new cycle every tick; both
    are rejected now
    - the USCI state interrupt lost START when STOP was pending as well
    - PID integral windup: the integral was limited to int32, far beyond the
    output rang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
    [i2c-slave.cpp, i2c-slave_hd.cpp]
2026-10-12 Move I/O out of constructors to separate init methods
    HardwareReal, FrontDisplayDemon and BrightnessDemon talked to the I2C
    bus or the database from their constructors via runBlocking. Demon now
    has init(), called by main.kt right before createJobs, and HardwareReal
    has its own init(). Burn mode initializes only the front display, so
    the board being updated is not touched.
2026-10-22 Add Geiger tube random bit generator
    Each pair of intervals between discharges gives one bit, the comparison
    is inverted on every other bit. The bits are stored in a 64-byte ring
    buffer and read with the new GET_RANDOM_BITS I2C command (up to 104 bits
    per read, removed once read). octoglowd gets Geiger.getRandomBits().
2026-10-22 Fix stale content drawn on the front display after a view switch
    The automatic view cycle redrew the old view instead of the new one, so the
    new view's status and instant updates were painted over the old screen.
    StateMachine runs onTransition after releasing its lock, so a draw request
    made in an older state could arrive after a view switch and either replace
    the new view's full redraw or be painted over it. Such requests are now
    dropped when queued and again before drawing.
